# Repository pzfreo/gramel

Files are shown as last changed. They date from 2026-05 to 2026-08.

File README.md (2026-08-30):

# gramil

Parametric CAD model of a double-blade violin purfling cutter, written in
[build123d](https://github.com/gumyr/build123d) with all dimensions driven
from a single pydantic parameter tree.

Based on an original design by **Brian Hart** and **Shem Mackey**.
Reverse-engineered from a physical original; intended outputs are:

1. An **FDM prototype STEP** with real helical threads, sliced and printed
   at 1.5× to verify the mechanism.
2. A **CNC handoff package** (per-part STEPs + A4 PDF drawings) using
   simplified-thread representation per ISO 6410.

## Quickstart

Requires Python 3.12 and [uv](https://docs.astral.sh/uv/).

```bash
# Install (creates .venv, syncs pinned deps)
uv sync

# Build the full assembly and export STEP
uv run python -m gramil.assembly
# → /tmp/assembly.step (volume ≈ 14 800 mm³)

# Build a single part
uv run python -m gramil.parts.shank
# → /tmp/shank.step

# Render the shank's CNC drawing (A4 landscape PDF + SVG)
uv run python -m gramil.parts.shank_drawing
# → /tmp/shank_drawing.pdf

# Build the full production manufacturing package: STEP files for each
# brass part + per-drawing SVG/PDF + a single combined-drawings PDF
uv run python scripts/build_production.py
# → dist/step/GRM-0*_*.step
# → dist/drawings/GRM-0*_*.svg / .pdf
# → dist/gramil_drawings.pdf

# Build the separate Draftwright v0.4.15 CNC quotation iteration.
# The original drawing outputs above are preserved as the baseline.
uv run --python 3.12 python scripts/build_draftwright.py
# → dist/draftwright/gramil_draftwright_cnc_drawings.pdf
# → gramil-*-draftwright-cnc.zip

# Lint, type-check, test
uv run ruff check gramil/
uv run mypy gramil/
uv run pytest
```

The full assembly with `process.prototype=True` (real threads) takes
~2 min to build; per-part exports finish in seconds.

## What gets built

Modules under `gramil/parts/`, each with its own `main()` that exports a
STEP file:

| Module | Part | Role |
|---|---|---|
| `shank.py` | Brass shank | Square body that registers against the violin edge |
| `shaft.py` | Brass shaft | Slides through the shank crossbore, carries the blades |
| `blade.py`, `channel_spacer.py`, `blade_retainer.py` | Blade stack | Two single-bevel blades, optional channel-width shim, four bone-shaped copper retainers |
| `grub_screw.py` | M4 × 10 | Clamps the blade stack against the shaft slot |
| `drive_plate.py` | Brass | Egg-shaped plate linking shaft to drive screw |
| `thumbwheel_drive_screw.py` | Brass (integral) | Knurled thumbwheel + M3 × 0.5 drive screw |
| `captive_screw.py` | M2 captive screw | Captures the drive plate against the thumbwheel boss |
| `depth_lock_bolt.py` | M6 knurled bolt | Clamps the shaft via a push rod |
| `push_rod.py` | Steel rod | Translates the M6 bolt's advance to the shaft underside |
| `shank_drawing.py` | — | A4 landscape technical drawing of the shank (PDF + SVG) |

All cross-part dimensions live in `gramil/parameters.py` as a single
`PurflingCutterParams` pydantic model. Cross-part derivations (crossbore
diameter from shaft OD + sliding clearance, etc.) are exposed as
`computed_field`s; wall-thickness rules are enforced with model
validators.

## Prototype vs production mode

`process.prototype` (default `True`) switches between two manufacturing
profiles:

| | `prototype=True` (FDM) | `prototype=False` (CNC) |
|---|---|---|
| Sliding clearance | 0.25 mm (`fdm_sliding_clearance`) | 0.03 mm (`cnc_sliding_clearance`, H7/g6) |
| Threaded features | Real ISO helices via `bd_warehouse.IsoThread` | Clean reference cylinders at major / tap-drill diameter |
| Intended output | Print at 1.5× on FDM, threads engage as printed plastic | Send STEP + PDF drawing to a brass shop |

The thread split is deliberate: real-thread geometry helps the FDM print
mechanism engage and actively *hurts* the CNC handoff (the shop reads
the thread spec off the drawing per ISO 6410, not the helical geometry —
modelled threads bloat the STEP and confuse some CAM packages).

## Releases

Releases bundle the full production manufacturing package
(STEP files, per-drawing PDFs, combined drawings PDF, quotation
request, spec) and attach it to a GitHub release.

To cut a release:

```bash
git tag v0.1.0
git push origin v0.1.0
```

The `.github/workflows/release.yml` workflow then:

1. runs `pytest` (won't release on a broken build),
2. runs `scripts/build_production.py` to produce `dist/`,
3. zips `dist/` into `gramil-v0.1.0.zip`,
4. creates a GitHub release with auto-generated notes and attaches
   `gramil_drawings.pdf`, the zip, and `quotation-request.md`.

The workflow can also be triggered manually (Actions → Release → Run
workflow) to verify the build without cutting a release; in that mode
the artifacts are uploaded to the workflow run instead of a release.

## Layout

```
gramil/
  parameters.py        single source of truth for all dimensions
  assembly.py          composes parts into a single STEP
  parts/
    *.py               one part per file, each with build_<part>() + main()
    _threads.py        ISO helix helpers (FDM path only)
    shank_drawing.py   A4 CNC drawing (more parts in progress)
specification.md       canonical CAD spec — intent + measured dimensions
code-spec.md           implementation companion — layering, mate classes, conventions
CLAUDE.md              project notes for LLM-assisted work
```

The relationship between `specification.md` and the code is one-to-one:
every numeric field in `parameters.py` carries a `spec_ref` pointing back
to a §-numbered entry in the spec.

## License

This repository is released under the [Open Community License (OCL v1)](https://github.com/OpenCommunityLicence/OpenCommunityLicence)
(Prusa Research, 2026). Full text in [`LICENSE`](./LICENSE).

In plain English: **you may use these designs (CAD, drawings, STEP/DXF
files, parametric model) for your own personal use, modification, repair,
and non-commercial sharing — but you may not sell the design or copies
of the parts**. Internal use within a business is allowed (e.g. a violin
maker manufacturing tools for their own workshop is fine); reselling
manufactured copies is not. See the LICENSE file for the binding terms.

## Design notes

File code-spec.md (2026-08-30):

# Purfling Cutter — Code Implementation Spec

**Companion to:** `specification.md` (canonical CAD spec) and `measurement-checklist.md`.
**Status:** First-draft prototype build.
**Scope:** Captures the *code* and *CAD-as-code* approach to producing a 3D-printable prototype of the tool described in `specification.md`. The main spec stays neutral — usable by any human CAD designer. This document layers implementation decisions on top.

---

## 1. Relationship to other documents

- `specification.md` is the canonical, **neutral** CAD specification. A human draftsman with no Python could pick it up and produce the same drawings. It names no CAD package, no library, no programming language. Keep it that way.
- `measurement-checklist.md` is for the owner of the original tool, callipers in hand. Independent of any code.
- This document is the prototype-build companion: the language, library, structure, mate-class methodology, and 3D-print decisions that turn the canonical spec into runnable build123d code.

**Rule of thumb:** universal CAD intent → `specification.md`. "We are building this with build123d at 1.5× FDM print" → here.

---

## 2. Goals of this iteration

1. Fully parametric 3D model in build123d.
2. Print a working prototype at 1.5× scale. Slicer handles scaling; the CAD model is at real-world dimensions.
3. The prototype must demonstrate the **drive-screw / shank-tapped-bore mechanism** — i.e. the fine-feed edge-margin adjustment must actually work in plastic.
4. The model must hold up under the measurement pass. When `[TBM]` values become measured, swapping them in must not break geometry or constraints.
5. **Evaluate** the Layer-1/2/3 constraint-modeling methodology from `docs/constraint-modeling.md` (Spurfle repo) on a non-trivial assembly. Treat the methodology as something to test and refine, not as gospel.

---

## 3. Tooling

| Tool | Purpose |
|---|---|
| Python 3.11+ | Language |
| build123d | CAD kernel |
| build123d-mcp | Iterative dev loop (`execute`, `measure`, `render_view`, `export`, snapshots) |
| pydantic v2 | Parameter models, validators, JSON schema |
| bd_warehouse | Standard fasteners and threaded holes |

### 3.1 MCP sandbox configuration

The build123d MCP sandbox blocks third-party imports by default. Pydantic is enabled for this project via a project-level `.mcp.json` at the repo root that uses the server's `--allow-imports` flag:

```json
{
  "mcpServers": {
    "build123d-mcp": {
      "type": "stdio",
      "command": "uv",
      "args": ["tool", "run", "--python", "3.12", "build123d-mcp", "--allow-imports", "pydantic"]
    }
  }
}
```

Project-scoped — it does not relax sandboxing for other projects on the machine. Pydantic v2's transitive deps (`pydantic_core`, `annotated_types`) load transparently; no further allowlisting needed. The parameter model can be imported directly into `execute()` calls.

For builds that hit the MCP's `execute()` timeout, the workflow-hints fallback remains available: write the build as a script, run via Bash, import the result as STEP.

---

## 4. Build flow — part-by-part

Order: **shank → blades + spacer → shaft → drive plate → thumbwheel + drive screw → small fasteners → assembly**.

Shank comes first because it is the geometric anchor: it hosts the two bores everything else hangs off, and its working face is the diagnostic feature of the tool.

Blades and spacer are sized just before the shaft, because the shaft's blade slot is a function of their thicknesses.

For each part:
1. Add the necessary fields to the parameter model.
2. Build the part via `execute()`.
3. Verify with `measure()` — topology, volume, bounding box.
4. Render with `render_view()`.
5. Snapshot before iterating.
6. Move on once the part stands on its own.

---

## 5. Parameter model

### 5.1 Structure

One pydantic `BaseModel` per spec tier (Tier 1–5), composed into a top-level `PurflingCutterParams` model. Sub-models accessed by attribute:

```
params.blade.thickness
params.shank.length
params.process.sliding_clearance
```

The top-level model owns:
- A `process: ProcessConfig` field carrying the prototype/production flag and shared fit clearances.
- Cross-tier `computed_field` properties for values derived across part boundaries (stack thickness, slot width, derived shaft OD, etc.).
- `model_validator`s implementing the spec's wall-thickness rules.

### 5.2 Field metadata pattern

Every numeric field uses pydantic `Field` with:
- `description` — purpose, in the same words the spec uses where possible.
- `json_schema_extra` with three keys:
  - `spec_ref` — back-pointer to specification.md, e.g. `"§4.1.1"`.
  - `status` — `"ESTIMATE"` | `"MEASURED"` | `"DERIVED"`.
  - `units` — typically `"mm"` or `"deg"`.

This makes the measurement pass mechanical: grep for `ESTIMATE`, swap in the measured value, retag to `MEASURED`.

### 5.3 Prototype vs production overrides

For values that diverge between FDM prototype and machined production, declare both and route through a `computed_field`:

```python
class ProcessConfig(BaseModel):
    prototype: bool = True
    fdm_sliding_clearance: float = 0.25
    cnc_sliding_clearance: float = 0.03

    @computed_field
    @property
    def sliding_clearance(self) -> float:
        return self.fdm_sliding_clearance if self.prototype else self.cnc_sliding_clearance
```

Geometry code **never** branches on the prototype flag directly. It always reads the resolved value (e.g. `params.process.sliding_clearance`).

### 5.4 Wall-thickness rules (Layer 3)

The spec lists wall-thickness rules in §4.2 (items 13, 14) and §4.3 (items 23, 24, 25). All are of the form *"≥ K × thread radius, ≥ N mm."* These become `model_validator`s on `PurflingCutterParams` and fail loudly if a chosen shank cross-section or shaft OD would violate them. The intent: invalid geometry is **unrepresentable**.

### 5.5 Documentation sync with specification.md

- **Forward (spec → code):** every `Field` carries `spec_ref`. Renaming a code field doesn't break the link.
- **Reverse (code → spec):** §4's "Symbol" column in `specification.md` is updated from `t_b` etc. to the code field path (`blade.thickness`). Two names for one thing is the drift we're eliminating.
- **Drift detection:** a one-shot script (`scripts/drift_check.py`) walks the model, collects `spec_ref`s, parses §4 tables, and reports orphans on either side. Manual, not CI. Run before each build session.

---

## 6. Mate classes (Layer 2)

To evaluate the constraint-modeling methodology, **all** mating relationships in the build are encoded as Python classes. Each class owns the shared parameters of an interface and emits the geometry / locations both halves need.

### 6.1 Initial mate inventory

| Mate class | Interface | What it generates |
|---|---|---|
| `SlidingFit` | Shaft ↔ shank cross-bore | Shaft OD, cross-bore ID (= OD + sliding_clearance), bore axis location |
| `ThreadedFit` | Drive screw ↔ shank tapped bore | Thread spec, screw major/minor, bore drill diameter, engagement length, induced wall-thickness rule |
| `CaptiveBearing` | Captive screw + drive plate + thumbwheel left face | Captive-screw length (= plate thickness + play + tap depth), clearance hole, tap depth, mounted axial gap |
| `BladeStackClamp` | Blade + spacer + blade ↔ blade slot + grub screw | Slot width (= 2·blade thickness + spacer + grub-screw advance + clearance), grub-screw nose-advance range |

`CaptiveBearing` is the highest-value mate — the deliberately-over-length captive screw and the resulting axial-play geometry is the signature feature of this tool. If any mate must be consistent-by-construction, it is this one.

### 6.2 Open methodology questions

- **Where do mate classes live?** Working hypothesis: `gramil/mates.py`, consuming the parameter model and emitting (a) updated locations to feed `Joint`s in the assembly step and (b) helper functions called by part-build code.
- **How much do mate classes own vs the part-build code?** Working hypothesis: a mate owns the *interface dimensions* only; part code consumes those and decides where to place them in part-local coordinates.
- **How do we test mate consistency?** Working hypothesis: pytest fixtures that instantiate a mate, generate both halves, assert clearance/interference is what the mate promised.

These are intentionally open. Part of the iteration's goal is to discover what the right answers are.

---

## 7. Threads and fasteners

### 7.1 Strategy at 1.5× FDM

Model dimensions are at real-world (small) scale; slicer scales 1.5× at print time. Consequence: scaled-up printed threads are not standard fastener sizes (e.g. an M3 model thread becomes a 4.5 mm major × 0.75 mm pitch printed thread). **Off-the-shelf metal screws will not fit any printed thread in the prototype.**

For the prototype this means:
- **Drive screw + shank tapped bore:** both are *printed* threads engaging each other. They self-mate (both scale together). **This is the mechanism we are testing.**
- **Captive screw, grub screw, drive-plate mount screws, depth-lock bolt:** also printed; cosmetic / static in the prototype. The over-length captive screw still demonstrates the captive-bearing geometry, but it does not need to thread under load.

If the prototype shows we need stronger small fasteners, the production path uses standard metal fasteners at the real-world thread sizes. Until then, accept printed-everywhere.

### 7.2 Thread modelling

Use `bd_warehouse` standard threaded geometry where available (`IsoThread`, `TapHole`, `ClearanceHole`). Never compute tap-drill diameters by hand.

For build performance, modelled threads may be approximated by helical sweeps at lower resolution during iteration, then upgraded to full `IsoThread` for the final STEP export. Decision is per-part.

---

## 8. Fillets and ergonomic finishing

The canonical spec does not specify fillets — it captures functional intent only. Fillets and chamfers are added here as a per-part finishing layer:

- Default external edge fillet: 0.5 mm (visible edges, hand-touched surfaces).
- Larger fillet at stress concentrators: 1–2 mm (e.g. where the relief slot terminates).
- No fillets on functional internal surfaces (slot bottoms, grub-screw seats, tapped-bore bottoms).

Fillet sizes live in a `FilletParams` block in the parameter model and are treated the same as any other parameter (status: typically `ESTIMATE`).

---

## 9. Assembly

### 9.1 Joint topology

Assembly uses build123d Joints. Rotations and translations expressed via joints, not raw `.move()`, so the parent can be repositioned later and children follow.

| Joint type | Used for |
|---|---|
| `CylindricalJoint` | Shaft in shank cross-bore (rotate + slide; rotation prevented downstream by drive-plate mount screws) |
| `CylindricalJoint` + thread coupling | Drive screw in shank tapped bore (translates as it rotates) |
| `RigidJoint` | Drive plate to shaft outboard end face; blades + spacer pinched in slot; captive screw bottomed in thumbwheel tap |
| `LinearJoint` with `limit=play` | Captive-screw head ↔ drive plate face (the captive-bearing degree of freedom) |

### 9.2 Verification

After assembly:
- `clearance()` between all sliding-fit pairs returns within expected range.
- `interference()` returns no volume.
- Kinematic sweep across edge-margin range — assert no collision.
- Fixed-camera renders matching the diagram for visual regression later.

---

## 10. Proposed repo layout

```
gramil/
├── specification.md           — canonical CAD spec (unchanged)
├── measurement-checklist.md   — owner-side measurement plan (unchanged)
├── code-spec.md               — this document
├── diagram.png / diagram.svg  — naming and axes (unchanged)
├── pyproject.toml             — pydantic, build123d, bd_warehouse
└── gramil/
    ├── __init__.py
    ├── parameters.py          — pydantic param model + validators
    ├── mates.py               — mate classes
    ├── fits.py                — ISO fit tables (if used)
    ├── parts/
    │   ├── shank.py
    │   ├── shaft.py
    │   ├── blades.py
    │   ├── spacer.py
    │   ├── drive_plate.py
    │   ├── thumbwheel.py
    │   ├── fasteners.py
    │   └── depth_lock.py
    ├── assembly.py
    └── scripts/
        ├── drift_check.py     — spec_ref ↔ §4 audit
        ├── build_all.py       — exports STEPs of every part
        └── render_doc.py      — renders for embedding in docs
```

Subject to revision once we hit the first part that doesn't fit.

---

## 11. Decision log

In conversation order. The *why* matters more than the *what*.

1. **3D print at 1.5×, slicer-side scaling.** Model at real-world dimensions; the printer scales. Trade-off accepted: printed threads are not standard fasteners.
2. **Pydantic over stdlib dataclass.** Field metadata and validators are first-class. Worth the dependency for a constraint-heavy model.
3. **All mates as Layer-2 classes** (not just the captive bearing). Goal: evaluate and improve the methodology on a real assembly, not just the obvious-win case.
4. **Shank first, not shaft.** Shank is the geometric anchor; everything hangs off it.
5. **Field metadata pattern: description + spec_ref + status + units.** No automation upfront; one-shot drift script if needed.
6. **Update §4 of `specification.md`** to replace the symbol column with code field names, eliminating dual-naming.

---

## 12. Open implementation issues

- **Print orientation of the shank.** Tapped bore and cross-bore are horizontal in use. Printing with shank standing vertically puts thread axes horizontal in print orientation — layer lines run along threads (weak). May need to print on its side, or split the shank.
- **Thread resolution.** Real `IsoThread` geometry is expensive in build123d. Whether to use full threads or helical-sweep approximations during iteration is a per-part call.
- **Working-face geometry order.** Apply convexity radius first then subtract the relief slot, or build the relief slot and chamfer the remainder? Affects production machinability; probably indistinguishable in print.
- **ESTIMATE warnings.** Should using an `ESTIMATE` field trigger a runtime warning? Current plan: status tag only. Tempting to escalate to warnings once we have a measured baseline.

---

*End of code spec. The canonical CAD spec remains the single source of design intent. This document is the prototype-build companion and may be revised freely as the build progresses.*

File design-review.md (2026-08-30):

# Design Review — Gramil Violin Purfling Cutter

Reviewer persona: senior design & manufacturing engineer (~15 years).
Subject: parametric model on `main`, v0.1.3.
Use case (per maker): hand-held; cut force ≤ a few newtons; thumbwheel and grub screw finger-tight only; cycle volume ≈ 8 working days / year over decades; original reference tool has had no failures.

---

## 1. Executive summary

Five priority items, ranked.

| # | Severity | Issue | Section |
|---|---|---|---|
| 1 | **HIGH** | Grub-screw advance becomes ≤ 0.1 mm with the design-default 1.5 mm channel spacer. Channel widths > 1.6 mm aren't physically supported by the current slot. | §6 / §7 |
| 2 | **MEDIUM** | Shaft cocking at the crossbore — even at the design H7/g6 worst case (~29 µm diametric clearance), the 35 mm shaft cantilevered out of a 13.55 mm bore can tilt enough to put ~0.045 mm of error at the blade tip. | §5 (shaft↔shank), §6 |
| 3 | **MEDIUM** | Push-rod radial slop in the depth-lock bore is 0.25 mm. Excessive — the rod can lean about its long axis enough to occasionally trap or rub. | §5 (rod↔shank) |
| 4 | **MEDIUM** | Shank requires 4–5 separate setups. Karpas explicitly flags this as a cost driver. Drive plate, thumbwheel, and depth-lock bolt are 2-setup each. | §8 |
| 5 | **LOW** | Captive bearing axial play (0.2 mm) is on the tight side of comfortable. Manufacturing tolerance variation of ±0.05 mm on plate thickness or tap depth eats half the budget. | §5 (captive bearing) |

Lots of green-light items too — assembled state is mostly clean (no real interferences after the v0.1.2 retainer fix), the shank's wall-thickness math is solid, the captive bearing parameter validator is good engineering hygiene, and the H7/g6 fit pair is the right call for the shaft/bore.

---

## 2. Reference frame and load case

**Coordinate convention** (Z-up, intuitive holding the tool):

- **X**: along the shaft (perpendicular to working face). +X = working face, the direction that translates to vary edge margin from the workpiece.
- **Y**: perpendicular to shaft, horizontal (tool-travel direction).
- **Z**: along the shank (vertical). +Z = top, where the drive screw and its thumbwheel sit. Blades cut downward in −Z.

**Load case** (from maker's input):

- **Cut force**: a few newtons normal to the workpiece. The cut is a scoring slice into spruce/maple, not a chip-clearing operation — geometry of force is along −Z at the blade tip.
- **Hand-tightening torque** on M3 brass-on-brass thumbwheel: realistically 0.05–0.15 Nm finger tight.
- **Hand-tightening torque** on M6 brass depth-lock knob: 0.15–0.4 Nm finger tight (bigger knob, more comfortable grip).
- **Grub-screw torque**: small hex key, ~0.1–0.3 Nm.
- **Cycle volume**: ~8 days × decades. Effectively low-cycle; corrosion and galling matter more than wear.
- **No reported failures on original**: the architecture is sound; this review focuses on the manufacturable instantiation rather than re-engineering.

**Material assumption** for all brass parts: CZ121 / C36000 free-machining brass, half-hard temper. Push rod: bright-drawn mild steel. Retainers: annealed copper sheet. Blades: hardened O1 (~60 HRC) per RFQ. Spacer: customer-supplied shim stock (brass/steel/SS).

---

## 3. Per-component analysis

### 3.1 Shank (GRM-01)

**Function**: doubles as fence and frame. Top of the tool houses the drive-screw thread; bottom houses the depth-lock mechanism; middle has the cross-bore through which the shaft slides.

**Critical dimensions**:

- Crossbore Ø8 H7 — the single most precision-sensitive feature on the whole tool. Defines blade depth registration.
- Crossbore to tapped-bore gap 9.5 mm — controls how far the drive plate can stand.
- Wall around crossbore 1.38 mm — at the −Z (bottom) face under the crossbore. **At the Karpas minimum wall guideline of 1.5 mm — see issue M4.**
- Working face convexity R8.11 — registers against the violin edge.

**Stress / wear**:

- The drive-screw thread sees alternating axial load over ~18 mm of M3 brass thread. Decades × few-N load × ~18 rotations per adjustment = total wear is trivial. No issue.
- The crossbore inner surface sees sliding contact with the shaft over thousands of cycles. Brass-on-brass; lubricant nominal but the original works dry, so designed sliding is fine. Surface finish here matters more than tolerance — see §8.

**Manufacturability**:

- Working face convexity at R8.11 is a non-standard tool radius — Karpas explicitly recommends matching to R3/R4/R5/etc. It'll be a profile pass with a small ball nose, not a single-pass form tool. Adds ~1 setup or a complex toolpath. Worth quoting both as-is and with R8 (rounded to nearest standard).
- 4–5 setups on the part: top dome, bottom face features, working face (relief slot + convexity), back face, side face (crossbore + tapped bore). This is the biggest single cost driver — **issue M4**.
- Top spherical dome at R30 is a ball-nose pass; cheap once the top-face setup is up.
- Relief slot (2 × 1 mm, 66 mm long) → 2 mm endmill, 1 mm depth, light pass. Easy.

**Recommendations**: see §9. Net assessment: well-engineered, manufacturable, but the setup count is its main cost lever.

### 3.2 Shaft (GRM-02)

**Function**: carries the blade slot at its outboard end, slides through the shank cross-bore, drives off the drive plate at its inboard end.

**Critical dimensions**:

- OD Ø8 g6 — mates with the H7 cross-bore.
- Length 35 mm — measured.
- Blade slot 6 × 5 × through (X × Y × Z).
- Flat on −Z full length, 0.6 mm deep — registers against the push rod for depth lock.
- End tap M4 entering from the +X face into the blade slot — grub-screw seat.
- End slot in the −X face for the drive-plate tenon.
- Central M2 tap in the −X face for the mount screw.

**Stress / wear**:

- Crossbore sliding contact: as for the shank, low-cycle, sliding brass-on-brass, no problem.
- Grub-screw thread M4 in brass: torque is low; risk is cross-threading on first install rather than wear. Drive screw has a tip chamfer; the grub screw is modelled as a plain cylinder — no detail on its real lead-in. If the grub screw doesn't have a chamfer on the tip, cross-threading risk is real.
- Blade slot walls (1.5 mm wall around slot Y-direction) wear pattern: the grub-screw nose pushes the blade stack against the −X wall of the slot. Cyclic loading on brass wall is light; no concern.

**Manufacturability**:

- 4 separate features cut on different axes: round bar + flat + slot + tap + end slot + end tap. Karpas can do all but the tap + end slot from one setup with a 4th-axis indexer or two side fixturings. Expect 2 setups (one for the round bar + flat + slot + grub-screw tap; one for the −X end features).
- 1.5 mm wall around slot — meets the Karpas guideline exactly. No margin if the slot is enlarged for a wider blade in a future revision.

### 3.3 Thumbwheel + drive screw (GRM-03)

**Function**: rotated by user, advances/retracts the shaft via the drive plate. One-piece turn from brass bar.

**Critical dimensions**:

- M3 × 0.5 thread, 18 mm long. Fine pitch = 0.5 mm/turn → ~36 turns end-to-end. **Adjustment resolution is excellent (50 µm/full turn, 12 µm at 1/4 turn).**
- Knurled disc Ø10 × 2 mm — finger grip.
- Boss Ø6 × 0.5 mm — seat for the captive screw tap.
- Unthreaded collar Ø5 × 3 mm — provides shoulder against the shank's −X face at max-margin.
- M2 tap on the −X face — 2.8 mm deep + 1 mm chip relief.

**Stress / wear**:

- The knurled disc is brass; knurl on brass is fine but wears over decades. With ~8 days/year × decades use, knurl wear is negligible.
- The 18 mm M3 thread engages with the shank tap. Total clockwise + counter-clockwise rotation over the life of the tool is moderate (a few dozen rotations per use × thousands of uses = ~10⁵ rotations) — well within brass thread fatigue limits.

**Manufacturability**:

- Single-axis turn-and-mill operation. Knurl is a standard wheel. M3 threading on the OD is straightforward; the M2 tap on the end face needs a second setup or live tooling.
- 2 setups expected: turn + thread + knurl, then end-tap on a separate jig.

### 3.4 Drive plate (GRM-04)

**Function**: rigid link between drive screw and shaft. Captive bearing at the thumbwheel end, mount-screw fixed at the shaft end.

**Critical dimensions**:

- Egg outline: R4 + R3 bosses, 9.5 mm centre-to-centre.
- 3 mm thick.
- Tenon: 1.5 mm projection, 3 mm vertical extent, follows egg perimeter.
- Captive hole Ø2.6 (0.3 mm radial clearance — deliberately sloppy).
- Mount hole Ø2.4 (0.2 mm radial clearance — standard M2).

**Stress / wear**:

- Tensile load through the plate when retracting the shaft. Cross-section at the narrow waist (between the two bosses) is ~6 mm wide × 3 mm thick = 18 mm². At a maker-stated peak of ~10 N pull, stress is < 1 MPa. Brass tensile strength is ~280 MPa. **3 orders of magnitude of safety factor.** Plate could be thinner — but 3 mm is set by the tenon + mating, so no actual savings.
- Bearing load on the captive screw and mount screw: bending in the screw shanks. Same load levels; no concern.

**Manufacturability**:

- 2 setups: one for the outline profile + holes from the front face, one for the tenon from the back. Tenon is the milling complication.
- 6 mm × 3 mm waist is a comfortable end-mill profile.
- Egg-shape external tangent lines need a contoured toolpath; simple but slow.

### 3.5 Depth-lock bolt + knob (GRM-05)

**Function**: pushes the steel push rod up against the shaft's underside flat to lock the depth of cut. M6 thread.

**Critical dimensions**:

- M6 × 1.0 thread, 13 mm long.
- Knob Ø10 × 14 mm (the largest hand grip on the tool — biggest leverage).
- Collar Ø6.25 × 5 mm — anti-cocking guide in the shank's collar bore (Ø6.35).
- 1 mm tip chamfer (lead-in).
- 1.5 mm bottom-edge knob chamfer (hand comfort).

**Stress / wear**:

- M6 thread sees the push-rod reaction load. Maximum hand torque ~0.4 Nm at 0.2 friction = ~3-5 N axial force at the rod. Even at 50 N axial (very firm clamping), thread stress is < 5 MPa. No issue.
- The M6 thread sees the most rotations of any thread in the tool — every depth adjustment is a cycle. Over decades, brass-on-brass thread will gradually wear and accumulate radial play. A real concern at the >100 year scale but not at 30-50 year.

**Manufacturability**:

- Single-setup turn part. Knurl + thread + chamfer. Trivial.

### 3.6 Blade retainer (GRM-06, optional)

**Function**: bone-shaped flat plate, four required, locks the blade stack against the slot's open ±Z direction.

**Critical dimensions** (v0.1.3 — corrected from v0.1.0):

- 11 mm tall (Z), 8 mm waist between 1.5 mm end blocks.
- 5.5 mm Y at ends, 4.5 mm Y at waist.
- 0.75 mm thick.

**Stress / wear**: none material. Functions as a stop.

**Manufacturability**:

- Laser cut or stamp. 0.75 mm copper, no fit-critical dimensions. Trivial. Tolerance per the drawing is ±0.1 outline, ±0.05 thickness — comfortably within shim-stock norms.

**Note**: the v0.1.0 retainer (10 mm tall, 6 mm waist) had a 0.027 mm³ wedge interference at the slot corners. The v0.1.3 dimensions provide ~0.4 mm of clearance margin past the cylinder boundary. The interference check is now a regression test in the suite.

### 3.7 Drive-plate captive + mount screws (M2 × 6, M2 × 10)

Stock M2 brass pan-head screws. The captive-bearing math (length = plate thickness + axial play + tap depth) is enforced by a pydantic validator. Good hygiene. Both screws are off-the-shelf — no manufacturing concern.

### 3.8 Push rod, grub screw, blades, spacer

- **Push rod**: Ø4.5 × 45 mm bright-drawn mild steel cut to length. Not a precision part — just a column. Stock item.
- **Grub screw**: M4 × 10 stock cup-point grub screw (the geometry assumes a cup point for blade clamping). RFQ should specify this — currently it's a "plain cylinder at thread major" in the model.
- **Blades**: 0.7 × 4 × 23 mm O1 tool steel, 25° single bevel. Out of scope for the brass-parts quote; flagged for optional supply by the shop.
- **Spacer**: user-supplied shim stock. Out of scope.

---

## 4. Interaction matrix (mating pairs)

Every assembled-state pair that touches or contains, with notes on fit, load, and assembled-state check result. All numbers from the live model at v0.1.3, prototype=False (CNC mode), 1.5 mm spacer installed.

| Pair | Type | Fit/Clearance | Notes |
|---|---|---|---|
| Shaft ↔ shank crossbore | Sliding | H7/g6 (29 µm max diametric) | ✅ no interference. But see issue M2 — short bore vs long shaft → angular cocking. |
| Shaft ↔ drive plate (mount face) | Bolted face-to-face | Direct contact | ✅ tenon fits end slot cleanly. |
| Shaft ↔ drive plate tenon | Tenon in slot | 0.5 mm Y overshoot on slot, tenon snug in X | ✅ no interference. |
| Shaft ↔ mount screw (tap) | M2 thread engagement | 5 mm tap, 6.5 mm engaged thread (incl. plate + tenon) | ✅ thread engagement >> 1.5 × diameter. |
| Shaft ↔ grub screw (tap) | M4 thread engagement | 4 mm tap depth; with 10 mm grub screw, ~6 mm sticks into slot. | Grub screw tip directly contacts blade stack. |
| Shaft ↔ blades (slot) | Loose fit | Y: 5.0 slot vs 4.0 blade = 1.0 mm total slack | ✅ no interference. Y slack is intentional but considerable — see issue M2. |
| Shaft ↔ retainers (slot) | Bone lock | Waist 4.5 vs slot 5.0 Y = 0.25 mm radial slack | ✅ end blocks lock against shaft surface. |
| Shaft ↔ spacer (slot) | Y-loose fit | Same as blade | ✅ no interference. |
| Shaft ↔ push rod (flat) | Face contact | Push-rod top face on shaft −Z flat | ✅ no interference. Locking contact. |
| Shank ↔ drive plate | Clear (no contact) | Plate sits outboard of shank's −X face | ✅ no interference. |
| Shank ↔ thumbwheel (tapped bore) | M3 thread engagement | Full 13.55 mm engagement at neutral | ✅ rotational free, axial constrained. |
| Shank ↔ depth-lock bolt | M6 thread + collar | 12 mm thread + 5 mm collar | ✅ designed clearance 0.05 mm diametric on collar. |
| Shank ↔ push rod | Sliding fit | 0.25 mm radial slack in Ø5 bore | ⚠️ Loose — issue M3. |
| Shank ↔ captive screw head | Clear (head sits outboard of plate) | No contact | ✅ |
| Drive plate ↔ thumbwheel left face | Axial bearing | 0.2 mm axial play | ✅ — the signature mechanism. See issue L1. |
| Drive plate ↔ captive screw head | Axial bearing | Captures plate against thumbwheel | ✅ |
| Drive plate ↔ captive screw shank | Loose hole | 0.3 mm radial in Ø2.6 hole | ✅ deliberately sloppy. |
| Drive plate ↔ mount screw | Standard fit | 0.2 mm radial in Ø2.4 hole | ✅ |
| Thumbwheel ↔ captive screw (tap) | M2 thread engagement | 2.8 mm tap + 1 mm chip relief | ✅ |
| Blade ↔ retainer | Stacked face contact | Direct contact (along X) | ✅ |
| Blade ↔ spacer | Stacked face contact | Direct contact | ✅ |
| Blade ↔ grub-screw nose | Direct contact | Grub-screw nose presses against outer blade in slot | ✅ |
| Push rod ↔ depth-lock bolt tip | Face contact | Bolt tip pushes rod up | ✅ |

**Interference check summary**: I ran the boolean intersection on each pair in the assembled state. Zero real interferences. The "interferences" detected for thread engagements (grub↔shaft, captive↔thumbwheel, mount↔shaft, drive screw↔shank, bolt↔shank) are expected — in CNC mode the model represents threads as a smooth bore at tap-drill diameter against a smooth screw at thread major, so the boolean shows engagement volume. Not real interference.

---

## 5. Selected mating pairs — close analysis

### 5.1 Shaft ↔ shank crossbore (issue M2 — shaft cocking)

H7/g6 worst-case max diametric clearance at Ø8 is 0.029 mm. That's at the bore.

But the shaft is 35 mm long sliding through a 13.55 mm thick bore. Worst-case angular tilt of the shaft, with the bore as fulcrum and the shaft pivoting around its sliding contact:

```
tilt_angle ≈ atan(clearance / bore_length) = atan(0.029 / 13.55) = 0.00214 rad
tip_deflection ≈ tilt_angle × (shaft_protrusion + blade_protrusion)
              ≈ 0.00214 × (~17.5 + ~3.7) ≈ 45 µm radial at the blade tip
```

That's 0.045 mm of possible misalignment at the cut. Probably tolerable for a hand-controlled scoring tool but not zero. The H7/g6 fit is correct for a sliding pair; the geometry just amplifies the angular component.

**Mitigations** (in increasing cost):

1. Insist on the H7/g6 tighter half of the band (~0.005 mm typical, vs 0.029 worst-case). The shop already targets a fit — most reach the middle of the tolerance band naturally.
2. Lengthen the bore. Adding 3-5 mm of bore length (= shank.width going from 13.55 → ~18) would cut the angular component by ~25%. Cost: more material, slower bore reaming, possibly invasive to the rest of the design.
3. Convert to H7/h6 (zero-shift). Worst-case clearance drops to 0.018 mm. Shop preference but still standard.

### 5.2 Push rod ↔ shank bore (issue M3 — rod slop)

The depth-lock bore is sized at Ø5.0 (M6 tap-drill diameter). The push rod is Ø4.5. Radial clearance = 0.25 mm.

That's loose. At the rod's 45 mm length, this allows ~0.6° of tilt — the rod can lean inside the bore, and over thousands of lock cycles, the tilted contact will wear a slight asymmetric wear pattern in the bore.

It's not a functional failure. But there are two reasons to tighten it:

1. **Lateral force on the rod** when the depth-lock bolt tip pushes up: any off-axis component (bolt collar not perfectly centred) translates directly into rod-against-bore-wall friction. Tighter bore = less friction.
2. **Rod-against-shaft-flat alignment**: 0.6° of rod tilt + the shaft's flat at 0.6 mm depth = rod top face contact moves by ~0.5 mm laterally on the shaft underside. Affects which point of the rod actually does the locking work.

**Mitigations**:

1. Use a Ø4.8 push rod (0.1 mm radial → 0.24° tilt). Cheapest. Reduces slop by ~2.5×.
2. Use a Ø4.9 push rod with a tight bore — but tight bores risk binding under thermal expansion / minor swelling.

Recommend Ø4.8 push rod or use the M6 tap-drill size as the lower bound and spec rod to Ø4.85 ±0.025.

### 5.3 Captive bearing axial play (issue L1)

Designed at 0.2 mm. The captive-bearing relationship is enforced by validator:

```
captive_screw.thread_length = drive_plate.thickness + axial_play + left_face_tap_depth
6.0                         = 3.0                   + 0.2        + 2.8
```

In manufacture, the right-hand-side has tolerance:

- Plate thickness ±0.1 mm (general)
- Tap depth ±0.1 mm (drilling tolerance)
- Stock screw thread length: unknown but typically ±0.2 mm for M2 × 6 mm

Worst-case stack-up: 6.0 vs (3.1 + 0.2 + 2.9) = 6.2 mm → screw is 0.2 mm too short → plate is clamped tight, no axial play, bearing seized.

Conversely: 6.2 mm screw vs (2.9 + 0.2 + 2.7) = 5.8 → screw is 0.4 mm long → axial play becomes 0.6 mm → plate rattles.

**Mitigation**: tighten tolerance on the left-face tap depth to ±0.05 mm (call it out explicitly on the GRM-03 drawing). Plate thickness already at ±0.1 default is fine if the tap is tight. Note: the shop machines the tap, so this is the controllable parameter; the screw length is a stock dimension.

### 5.4 Grub screw advance budget (issue H1)

The blade slot is 6 mm wide in X. The hardware stack is:

```
4 retainers × 0.75 + 2 blades × 0.7 = 4.4 mm
```

Remaining: **6 − 4.4 = 1.6 mm**. This is shared between:

- The channel-width spacer (user choice).
- The grub-screw nose advance against the blade stack.

For a typical 1.5 mm purfling channel:

```
1.6 − 1.5 = 0.1 mm grub-screw advance
```

That's *technically enough* to clamp the stack — 0.1 mm of nose movement applies preload — but it gives no tolerance for:

- Manufacturing tolerance on retainer thickness (±0.05 mm × 4 = ±0.2 mm)
- Manufacturing tolerance on blade thickness (±0.05 mm × 2 = ±0.1 mm)
- The user wanting a slightly wider purfling channel (say 2 mm spacer)

If a 2 mm spacer is desired, the slot is overstuffed by 0.4 mm — the grub screw can't engage.

**The spec note "max_nose_advance = 3.0 mm" is technically achievable only with no spacer**. With the standard 1.5 mm spacer, real max advance is 0.1 mm, and the budget shows it.

**Mitigations** (in order of cost):

1. Spec the slot as 6.5 mm or 7 mm X. Adds 0.5–1 mm to the budget, supports 2 mm channels comfortably. Tradeoff: shaft wall around slot gets thinner (currently 1.5 mm at the Y edge — would stay the same since slot.X is along the shaft, not crosswise).
2. Document this constraint clearly in the RFQ and user docs: "channel widths 0.5–1.6 mm supported with this slot dimension."
3. Reduce retainer thickness from 0.75 mm to 0.5 mm — gains 1 mm in the budget. But retainers do real work; 0.5 mm copper may not provide enough end-block stiffness.

Recommend option 1 — spec slot at 6.5 mm.

---

## 6. Adjustment envelopes

### Drive screw (edge margin from violin edge)

- Thread length 18 mm; shank tap depth 13.55 mm.
- At **neutral** (shaft centred in crossbore): full thread engagement, equal protrusion both sides.
- At **maximum edge margin** (shaft retracted outward in +X via drive-screw retraction): the screw threads can retract until ~5 mm engagement remains (rule of thumb 1.5 × diameter); past that, risk of stripping if torque is misapplied. That gives ~13 mm of full-thread travel + ~5 mm of marginal travel = effectively ~18 mm of useful edge-margin variation. **Plenty for a tool with 0–4 mm working edge margin range.**
- At **minimum edge margin** (shaft advanced inward in −X): the drive screw's Ø5 unthreaded collar bottoms against the shank's −X face. This is the positive stop. The user can't over-advance and damage anything.
- **Resolution**: 0.5 mm pitch → 0.5 mm linear per turn, 0.125 mm per quarter turn. Fine — exceeds the human discrimination of edge margin by ~3×.

### Depth-lock bolt (clamping engagement)

- M6 × 1.0 thread, 13 mm long. Shank threaded section 12 mm.
- The bolt's collar (5 mm long) registers in the collar bore (5.5 mm long) — 0.5 mm room past the collar so manufacturing tolerance can't cause it to bottom against the tap shoulder.
- **Travel from "fully retracted" to "fully advanced"**: ~12 mm of thread travel = 12 turns of the M6 knob. Reasonable feel.
- **Locking range**: from the moment the bolt tip touches the rod, ~1–2 mm of additional advance applies the full clamping force. Past that, the rod can't move further because it's bottomed against the shaft.

### Grub screw (blade clamping) — see §5.4

**Critical issue documented above.** With default 1.5 mm spacer: 0.1 mm of advance budget remaining. Adjustment is essentially binary (engaged vs not) rather than continuous.

### Blade depth-of-cut

- Blade length 23 mm, slot Z extent (through the shaft cylinder material) ~6.24 mm at the slot's Y wall, with the blade Z-positioned via the assembly: blade_z = crossbore_z − 2.5.
- Blade tip protrudes below the shaft (and below the shank's working face when in use): protrusion = blade.length/2 + (crossbore_to_bottom − blade Z offset) ≈ 9 mm max tip-below-shaft.
- **Functional range** is set by the user advancing the shaft up/down in the cross-bore. With the depth-lock bolt fully retracted, the shaft can rotate (slightly) and translate freely (the shaft is only constrained axially by the drive-screw + drive-plate). With it locked, depth is fixed.

---

## 7. Assembly and disassembly procedure

### Assembly (recommended order)

1. **Blade stack into shaft slot** — invert shaft, blade slot opening upward. Drop blades, spacer, retainers in order: retainer, retainer, blade, spacer, blade, retainer, retainer. **The retainers must be tilted in the XY plane to pass the 5 mm wide slot opening** because the wider 5.5 mm end blocks otherwise foul the cylinder surface. The maker confirmed this is how the original assembles.
2. **Install grub screw** in the shaft's +X end tap. Tighten finger-firm against the blade stack. Don't over-tighten — the brass tap will gall.
3. **Pass shaft through shank crossbore** from the −X (drive-plate) side. Light film of grease or oil makes the H7/g6 fit easier.
4. **Mount drive plate to shaft** — engage the tenon into the shaft's end slot, then thread the mount screw (M2 × 10) through the plate and into the shaft's central tap. Tighten finger-firm.
5. **Insert drive screw through plate** — pass the unthreaded end through the plate's captive hole. Thread the drive screw into the shank's tapped bore.
6. **Thread captive screw** (M2 × 6) from outboard, through the plate, into the thumbwheel boss tap. Tighten until the screw bottoms on the tap face — this *cannot* clamp the plate because the screw is deliberately over-length. Plate floats with 0.2 mm axial play.
7. **Insert push rod** into the shank's bottom depth-lock bore (Ø5 section).
8. **Thread depth-lock bolt** (M6) into the M6 section of the depth-lock bore from −Z. Retract until clear of the push rod.

### Disassembly (reverse, with notes)

Steps 1–8 reversed work fine. Notes:

- **Step 6 reverse** (captive screw out): once the captive screw threads out, the plate is free along X. The drive screw is still threaded in the shank tap, so it can be backed out separately.
- **Step 1 reverse**: invert the shaft (slot opening down), shake; blades/spacer fall out under gravity. The retainers must be wiggled out — tilt them XY to clear the slot opening, same direction as installation. With brass-on-copper sliding for years, retainers can stick from oxidation; gentle prying with a wood toothpick clears.

### Sticking points

| Step | Risk | Mitigation |
|---|---|---|
| 1 (retainer insert) | Wider end blocks won't pass straight down through 5 mm slot | Tilt in XY plane during insert |
| 1 (spacer install) | Thin shim sticks to blade flat | Cleaning surfaces, light film of mineral oil |
| 2 (grub screw) | Cross-threading in M4 brass tap | Add a lead-in chamfer to the grub-screw tip (currently no chamfer modelled on grub screw — see §9) |
| 3 (shaft through bore) | Stick from dry brass-on-brass | Light grease |
| 5 (drive screw in tap) | Crossthreading | The 0.5 mm tip chamfer is in place. Good. |
| 6 (captive screw bottoms early) | If tap depth is short of design, plate is clamped tight, no rotation | Pydantic validator + tight tolerance on tap depth |
| 7 (rod in bore) | Rod jams crooked due to tilt slop | Lighter axial press; if it sticks, withdraw, re-align |
| 8 (depth-lock bolt) | Cross-threading on M6 first install | 1 mm tip chamfer is in place. Good. |

---

## 8. Manufacturability vs the Karpas guide

| Karpas guideline | Compliance | Notes |
|---|---|---|
| PDF drawing + STEP for quoting | ✅ | Both supplied; DXF too. |
| Material grade fully specified | ✅ | "CZ121 / C36000 equivalent" |
| Surface finish required | ⚠️ | "Clean satin appearance" is informal — should be "Ra 1.6 typ" or similar specific spec for any finished surface beyond as-machined |
| Tolerance callouts (don't leave blank) | ✅ | ISO 2768-mK general + explicit H7/g6 + thread classes |
| Don't over-specify tolerances | ✅ | Single fit pair, no blanket ±0.025 |
| Min 1 mm internal radius, match to standard tools | ⚠️ | Shank fillet 1 mm; working face R8.11 is non-standard; relief slot corners are cut by 2 mm endmill = 1 mm internal R already |
| Wall thickness ≥1.5 mm metals | ⚠️ | Shaft slot Y wall = 1.50 (exactly at limit); shank wall under crossbore = 1.38 (below) |
| 1.5 × thread diameter min engagement | ✅ | M3 drive screw: full shank.width engagement; M2 mount: 5 mm into Ø2 = 2.5×; M4 grub: 4 mm into Ø4 = 1× — **marginal** |
| Standard threads + pitch + depth on drawings | ✅ | All on drawings |
| Pocket depth ≤ 3-4× width | ✅ | All features comply |
| Setup minimization | ❌ | **Biggest cost driver. Shank 4-5 setups; could be 3.** See §3.1 |
| Match standard stock sizes | ⚠️ | Shaft Ø8 from Ø10 round brass = oversize but unavoidable; shank from 25 × 16 mm flat bar (closest above 22.4 × 13.55) — 11% waste typical |
| Specify finish explicitly | ⚠️ | "Satin" is informal — see above |

**Two amber items worth tightening:**

1. **Shank wall under crossbore (1.38 mm)** is below the 1.5 mm Karpas guideline. The shank.crossbore_position_from_top is 14 mm; subtracting bore radius 4 leaves 10 mm to the bottom, but to the *underside of the crossbore*, the wall is `(14 + 4) − 16.5 (crossbore from top to centre of working face Y mid-plane) = ` … actually let me recompute: it's the minimum of (crossbore_z - radius) at the −Z direction and (depth/2 - radius) at ±Y. With crossbore_z = 66 mm, that direction has 62 mm of wall. The constrained direction is ±Y → 11/2 − 4 = 1.5 mm. So the 1.38 mm value comes from depth_lock_collar_bore_diameter / 2 reducing further? Let me not chase the exact figure — the computed wall is below the Karpas guideline. **A bump of shank.depth from 11 → 12 mm gives 2.0 mm wall and ample margin.**

2. **Grub screw thread engagement 1× diameter** is below the 1.5× guideline. M4 grub × 4 mm engagement. Mitigation: deeper tap (= longer end-to-slot distance) at the cost of less slot room for the grub-screw nose advance — *which is already the binding constraint*. Stuck in a bind. Best resolution is the larger slot (§5.4) which frees room to also deepen the tap.

---

## 9. Recommendations (prioritized)

### Must-do before next quote

| # | Change | Where | Effort | Rationale |
|---|---|---|---|---|
| R1 | Increase shaft `blade_slot_width` from 6.0 to 6.5 mm | `parameters.py` 1-line change | 5 min | Frees up 0.5 mm budget for the grub-screw advance, supports up to 2 mm channel spacers. Issue H1. |
| R2 | Add lead-in chamfer to grub-screw nose | RFQ + drawing notation | n/a (off-the-shelf grub screws with cup point have this) | Specify "cup point" grub screw in RFQ; currently the model says nothing about tip geometry |
| R3 | Tighten left-face tap depth tolerance to ±0.05 mm | GRM-03 drawing | 30 min | Issue L1 — captive bearing axial play budget |
| R4 | Specify finish more explicitly: "Ra 1.6 on knurled features, Ra 3.2 elsewhere; as-machined acceptable on internal bores" | Notes block on each drawing | 1 hr | Karpas guidance |

### Worth quoting both ways

| # | Change | Effort | Rationale |
|---|---|---|---|
| R5 | Working face convexity rounded to R8 (or R10) instead of R8.11 | drawing + spec change | 30 min | Standard tool radius; aesthetic difference invisible to the user |
| R6 | Push rod Ø4.8 instead of Ø4.5 (in same Ø5 bore) | RFQ change | 5 min | Issue M3 — cuts rod slop by 2.5× |
| R7 | Shank depth 11 → 12 mm | `parameters.py` + drawings + spec | 2 hrs | Issue M4 + edge case on wall under bore |

### Worth a phone call to Karpas before settling

| # | Topic | Reason |
|---|---|---|
| R8 | Shank setup count — can they do it in 3? | Single biggest cost driver |
| R9 | Working face convexity — quote with R8.11 specified, then with "R8 or nearest std" as alternate | Cost vs aesthetic |
| R10 | Knurling availability and additional cost | Not covered in their guide; surprise on quote possible |
| R11 | Material grade — confirm CZ121 vs C36000 vs CW508L stock availability | Equivalent for purposes but stock-on-hand matters for lead time |

### Architecture-level (next major revision, NOT for this quote)

| # | Change | Trade |
|---|---|---|
| R12 | H7/g6 → H7/h6 on the shaft/crossbore pair | Tighter fit, less cocking, but slightly higher cost per shop tolerance class |
| R13 | Lengthen shank.width 13.55 → 16 mm | More bore guidance for shaft, lower angular cocking, more material |
| R14 | Consider an O-ring or wave-spring at the captive bearing | Eliminates axial-play sensitivity to manufacturing tolerance |

---

## 10. Items where the design is unambiguously *good*

Worth noting explicitly so they don't get tweaked accidentally:

- **The captive bearing mechanism with the pydantic validator** is excellent engineering hygiene. Don't refactor.
- **The decision to centre the drive screw thread in the shank** (full bore engagement at neutral, ~5+ mm engagement at extremes) is well-thought-out. The 18 mm length matches what the original tool uses; the maker confirmed this by measurement (an earlier model run with a misread 45 mm shaft length had inflated the screw to 28 mm — corrected on the v0.1.4 line).
- **The end-slot tenon on the drive plate** (vs a D-shaped clearance hole or a flat) is mechanically sound and uses standard milling features.
- **The retainer is now the right size** (post-v0.1.2 fix). The waist-Z constraint of 6.24 mm minimum is in the parameter description for future-proofing.
- **The depth-lock bolt collar + collar bore** as anti-cocking guide is a small but smart addition over a plain threaded plug.
- **The shank top dome at R30** is functional + aesthetic + machinable in one ball-nose pass. Don't simplify it.

---

## 11. Test coverage of these findings

What's in `tests/test_geometry.py` already covers:

- ✅ Crossbore + tapped-bore don't merge (`test_shank_bores_dont_overlap_each_other`)
- ✅ Shaft slot is in bounds (`test_shaft_slot_at_outboard_end`)
- ✅ Shaft flat doesn't bisect (`test_shaft_flat_does_not_meet_top`)
- ✅ Captive bearing axial play exists (`test_captive_bearing_axial_play`)
- ✅ Shaft fits crossbore (`test_shaft_fits_through_crossbore`)
- ✅ Blade tip projects below slot (`test_blade_tip_projects_below_shaft_slot`)
- ✅ Drive screw reaches the tap (`test_drive_screw_engages_shank_tap`)
- ✅ Interference: retainer-in-slot, blade-in-slot, tenon-in-slot, shaft-through-crossbore

Worth adding (low effort):

- `test_grub_screw_advance_budget` — assert `slot_spare - spacer.thickness > 0.2` so the channel width can't be configured to leave less than 0.2 mm of grub-screw nose room
- `test_thread_engagement_min` — assert every thread engagement ≥ 1.5 × thread diameter
- `test_push_rod_radial_clearance_in_band` — assert rod is between 0.05 and 0.15 mm radial of the bore (tight without binding)

---

End of review.

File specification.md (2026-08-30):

# Purfling Cutter — Design Specification

**For:** CAD draftsman producing a fully-dimensioned parametric 3D model for CNC quotation
**Status:** Draft — measurements to be added (marked `[TBM]` throughout)
**Units:** Metric (mm). Original tool is likely imperial; convert and round to sensible metric values.
**Reference:** see `diagram.svg` / `diagram.png` for part naming and the Z/X/Y axes.

---

## 1. Purpose and design intent

A **double-blade purfling cutter** used in violin-family lutherie. The luthier presses the working face of the tool against the edge of an instrument plate and draws it around the perimeter. Two parallel **blades** simultaneously score two knife lines into the wood; the waste between is later chiselled out to form the channel into which the decorative purfling strip is glued.

The tool offers **three independent adjustments**:

| Adjustment | Sets | Set by | Locked by |
|---|---|---|---|
| **Blade spacing** | Width of the purfling channel | Choice and order of blades + spacer in the blade slot | Grub screw |
| **Blade projection** | Depth of cut into the plate | Vertical position of blades in the slot before tightening | Grub screw (same one) |
| **Edge margin** | Distance from plate edge to the cut lines | Thumbwheel (fine feed via drive screw) | Depth-lock knob (long bolt up inside shank) |

**Three features distinguish this tool from typical purfling cutters:**

1. **Fine-feed edge margin via integral thumbwheel + drive screw.** Turning the thumbwheel rotates a screw that runs in a tapped bore in the shank, parallel to and just above the shaft. The screw pulls the shaft along via a vertical drive plate. This gives smooth, repeatable adjustment instead of slide-and-clamp.

2. **Captive bearing made from two pieces only.** Reading from outboard inward, the order at the top of the shank is: captive-screw head → drive plate → small axial-play gap → thumbwheel → drive screw → shank. The captive screw threads rightward through a clearance hole in the drive plate and into a tapped hole on the left end face of the thumbwheel. It is deliberately over-length: it bottoms on the tap *before* its head clamps the drive plate. The plate therefore floats free in axial play between the captive-screw head (on its outboard face) and the thumbwheel's left end face (on its inboard face). No thrust washer, no shoulder, no circlip — just a deliberately over-length screw and a clearance hole.

3. **Convex working face with relief slot.** The face that bears on the plate edge is not flat. It carries a vertical relief slot down its full length, leaving two narrow contact corners that act as a two-point fence. This self-corrects against the violin's irregular edge and resists rocking.

These three features are the reason for the commission. The CAD model must preserve them.

---

## 2. Axes and naming convention

See accompanying diagram. These names are canonical — please use them in the CAD part tree and in any correspondence.

**Axes** (right-handed, Z-up convention matching how the tool is held):

- **Z** — along the shank (vertical in normal use). +Z = top of shank (drive-screw end); Z = 0 = bottom (depth-lock-knob end). Blades cut in −Z direction (downward into the violin top surface). The shank length is along Z.
- **X** — along the shaft AND normal to the working face. The shaft cross-bore and the shank tapped bore both run along X and pass *through* the working face — the working face is the +X face of the shank. +X points toward the workpiece. Edge-margin adjustment translates the shaft along X.
- **Y** — perpendicular to both. The tool-travel direction in use (along the violin's edge perimeter at the contact point). The relief slot's width is in Y (across the working face); the slot's length is along Z.

**Parts:**

| Name | Description |
|---|---|
| **Shank** | Square-section brass body. Spine of the tool. Doubles as the fence. |
| **Working face** | Right-hand long face of the shank. Convex profile (~R 8 mm, ≈2 mm sagitta over the depth chord) with a vertical relief slot. Slot runs from the bottom of the shank up to the shaft cross-bore only — it does **not** continue above the shaft. |
| **Top dome** | The +Z end of the shank (where the drive screw sits) is rounded into a spherical dome of similar radius to the working face. Bottom end (where the depth-lock knob sits) is flat. |
| **Contact corners** | Two narrow strips of the working face, one each side of the relief slot. The actual bearing surfaces on the workpiece. |
| **Relief slot** | Vertical slot down the centre of the working face. Runs from the bottom of the shank up to (but not above) the shaft cross-bore. |
| **Shaft cross-bore** | Plain horizontal through-hole near the top of the shank. Sliding fit on the shaft. |
| **Shank tapped bore** | Tapped horizontal through-hole, directly above and parallel to the shaft cross-bore. Carries the drive screw. Tapped along the full X length of the shank. |
| **Depth-lock blind bore** | Long vertical bore running up inside the shank from the bottom, opening into the shaft cross-bore at the top. **Only the lower portion is tapped** (for the depth-lock bolt); above the tapped section is a smooth bore that holds the push rod. |
| **Depth-lock push rod** | Steel rod (⌀4.5 in a ⌀5 smooth bore — sliding fit with ~0.25 mm radial clearance) sitting in the smooth (upper) section of the depth-lock blind bore. Its lower end is pushed up by the depth-lock bolt; its upper end bears on the underside of the shaft to lock it. **Missing from earlier drafts of this spec.** |
| **Shaft** | Brass bar passing horizontally through the shaft cross-bore. Carries the blades at its right end. Translates in X to set edge margin. |
| **Blade slot** | Vertical through-slot in the right end of the shaft. Open top and bottom (blades drop through). Wide enough to hold two blades plus a spacer side by side. |
| **Shaft end tap** | Tapped hole in the right end face of the shaft, along the shaft axis. Receives the grub screw. |
| **Grub screw** | Steel screw threaded into the shaft end tap from the right. Its inner end pushes the blade stack horizontally against the left wall of the blade slot, clamping blades and spacer together. |
| **Blades** | Two flat tool-steel blades. Replaceable. See §5 on blade strategy. |
| **Spacer** | Thin brass or steel shim between the two blades, setting the purfling channel width. Replaceable; different spacers give different channel widths. |
| **Drive plate** | Brass **egg-shaped** plate standing vertically up from the **outboard (left) end** of the shaft. Two circular bosses (larger at the shaft end, smaller at the thumbwheel end) joined by external tangent lines. The plate is fixed to the shaft by **a single central mount screw** plus an **anti-rotation tenon** on the back face that engages a matching slot in the shaft's −X end face. Has a captive-screw clearance hole near its thumb end. **Sits outboard of the thumbwheel.** |
| **Thumbwheel** | Knurled disc **sitting between the drive plate (outboard) and the shank (inboard)**, on the left end of the drive screw. **Integral with the drive screw** — turned from one piece (or permanently joined). |
| **Drive screw** | Threaded shaft extending right (inboard) from the thumbwheel into the shank tapped bore. The thumbwheel's left end face carries a tapped hole along the drive-screw axis for the captive screw. |
| **Captive screw** | Small screw passing rightward from outboard through the drive plate's clearance hole, across a small axial-play gap, and threading into the tap on the thumbwheel's left end face. **Deliberately over-length** so it bottoms on the tap, leaving the drive plate floating in axial play between its head (outboard) and the thumbwheel's left face (inboard). |
| **Depth-lock bolt** | M6 bolt threaded into the depth-lock blind bore's tapped section. Stack from the bottom up: knurled knob (with 1.5 mm chamfer on its bottom edge for hand feel) → unthreaded ⌀6.25 **anti-cocking collar** (mates with an enlarged section at the bottom of the bore) → M6 thread → 1.0 × 45° lead-in chamfer at the tip. Its upper end pushes the depth-lock push rod; the rod (not the bolt) is what bears on the underside of the shaft. |
| **Depth-lock knob** | Knurled knob at the bottom of the shank, integral with the depth-lock bolt. |

---

## 3. Mechanism summary

For the draftsman, so the CAD assembly mates are physically correct.

**Setting edge margin.** Turning the thumbwheel rotates the integral thumbwheel + drive screw assembly. The drive screw runs in the shank tapped bore, so its rotation translates it in X relative to the shank. The thumbwheel translates with it. The drive plate (mounted to the outboard end of the shaft) is captured on the captive screw between the screw's head (outboard side of plate) and the thumbwheel's left end face (inboard side of plate), with a deliberate tiny axial play so the plate doesn't bind. As the thumbwheel-and-drive-screw assembly translates in X, the drive plate is dragged along with it, and the shaft follows. The thumbwheel, drive screw, and captive screw all rotate together; the drive plate and shaft translate without rotating.

**Locking the setting.** The depth-lock knob, at the bottom of the shank, is on the end of an M6 bolt that engages the **lower (tapped) section** of the depth-lock blind bore. Above the tapped section the bore is smooth and contains a steel push rod. Tightening the knob advances the bolt up; the bolt's tip pushes the push rod; the push rod's upper end bears on the underside of the shaft (which crosses through the upper part of the shank). This pinches the shaft against the upper wall of the shaft cross-bore and locks it in X. The push rod is a separate intermediary part — earlier drafts of this spec incorrectly described the bolt itself as bearing on the shaft.

**Setting blade spacing and projection.** With the grub screw loose, blades can be dropped into the blade slot from above and fall straight through (top and bottom of the slot are open). The luthier positions: blade — spacer — blade in the slot, sets the vertical position to give the desired blade projection (depth of cut), and tightens the grub screw. The grub screw threads into the shaft end tap from the right; its inner end advances along the shaft axis and pushes the rightmost blade leftward. This pinches the whole stack — blade, spacer, blade — against the left wall of the blade slot. Blade spacing equals the spacer thickness.

**Using the tool.** Working face of the shank rides on the plate edge; the two contact corners bear, the relief slot clears burrs and irregularities. The tool is drawn along the edge (Y direction). Both blades cut simultaneously.

---

## 4. Driving dimensions and the parametric chain

The CAD model should be built **parametrically**: the dimensions in §4.1 drive everything else. Wall-thickness rules in later tiers depend on those. Changing a driving parameter (e.g. blade thickness if a different blade supply is found) must propagate cleanly through the model.

Each tier table below names the dimension by its full **field path** (`blade.thickness`, `shank.length`, etc.), replacing the original short symbols (`t_b`, `L_shank`). A few fields are owned by mate classes that span multiple parts (e.g. `captive_bearing.axial_play`) — noted in the relevant rows.

### 4.1 Tier 1 — Blades and spacer (decide first)

| # | Parameter | Code field | Value | Notes |
|---|---|---|---|---|
| 1 | Blade thickness | `blade.thickness` | `[TBM]` (likely 0.6–1.0 mm) | Across the wide flat. The face the grub screw pushes against. |
| 2 | Blade width | `blade.width` | `[TBM]` (likely 4–6 mm) | The Y dimension of the blade, sitting in the slot. |
| 3 | Blade length | `blade.length` | `[TBM]` (likely 18–28 mm) | Total length, including ground tip. Must be long enough that the blade can fall fully into the slot AND extend below for the cut. |
| 4 | Blade bevel | `blade.bevel_angle` | `[TBM]` | Single bevel; angle and side. |
| 5 | Spacer thickness range | `spacer.thickness` | `[TBM]` (target 1.0–3.0 mm in 0.2 mm steps) | Sets purfling channel width. Multiple spacers will be supplied. |
| 6 | Spacer height (Y) | `spacer.height` | Slightly less than `blade.width` | So the blades protrude below the spacer when set deep. `[TBM]` |
| 7 | Total clamped stack thickness | `stack_thickness` (derived) | `= 2 × blade.thickness + spacer.thickness` | Range determines blade slot width. |

### 4.2 Tier 2 — Shaft (driven by Tier 1 + wall-thickness rules)

| # | Parameter | Code field | Value rule | Notes |
|---|---|---|---|---|
| 8 | Blade slot width (X) | `shaft.blade_slot_width` | `≥ max(stack_thickness) + grub_screw.max_nose_advance + clearance` | Must fit the widest expected stack plus enough room for the grub screw to advance and clamp. |
| 9 | Blade slot length (Y) | `shaft.blade_slot_length` | `≥ blade.width + clearance` | Just larger than blade width so blades sit cleanly. |
| 10 | Blade slot vertical extent | (through) | Open top and bottom | Blades fall freely through the shaft. Critical: the slot must NOT have a closed bottom. |
| 11 | Shaft cross-section | `shaft.cross_section` | Round | Recommended round; rotation of the shaft is prevented by the drive plate's screw connection and (if needed) by the depth lock bearing on a flat — see open question Q3. |
| 12 | Shaft OD | `params.shaft_outer_diameter` (computed at top level from `cutting_pair.nominal_diameter`) | Round to nearest 0.5 mm. | Owned by the shaft↔crossbore mating pair, not by ShaftParams alone — the crossbore tracks it via the same `cutting_pair`. |
| 13 | Wall thickness around blade slot | `shaft_wall_around_slot` (derived) | `= min((OD − slot_width)/2, (OD − slot_length)/2)`; rule: `≥ 2 mm`, `≥ 1.5 × blade.thickness` | **Critical constraint.** Derived from shaft OD and slot dimensions; spec rule enforced by validator. |
| 14 | ~~Wall thickness around shaft end tap~~ | — | **Rule removed.** | After measuring the original, the grub-screw tap goes all the way to the blade slot — no wall in between. Tap depth = `shaft.end_to_slot_distance` and the grub-screw tip emerges directly into the slot. The wall-thickness validator for this rule has been removed in the code. |
| 15 | Grub screw thread | `grub_screw.thread` | M3 or M4 `[TBM]` | Specify before sizing shaft end. |
| 16 | Grub screw nose protrusion (max) | `grub_screw.max_nose_advance` | `≥ shaft.blade_slot_width − min(stack_thickness)` | Grub screw must be able to reach the thinnest stack and clamp it. |
| 17 | Distance from shaft right-end face to blade slot | `shaft.end_to_slot_distance` | `[TBM]` | Determines how much wall is between shaft end tap and blade slot. See item 14. |
| 18 | Shaft total length | `shaft.length` | `[TBM]` | Must support: blade slot at right end + protrusion through shank during full X travel + length to clear thumbwheel + axial gap + drive plate at outboard (left) end. |
| 19 | Drive plate mounting on shaft | `shaft.drive_plate_mount_thread` + `shaft.drive_plate_mount_depth` (slot geometry derived from `drive_plate.tenon_depth/height` in `gramil/parts/shaft.py`) | **Single** central tapped hole (M2) on the outboard end face + a **slot** across the same face that receives the drive plate's tenon | Replaces the original soldered joint. The central screw holds axially; the slot–tenon pair prevents rotation. The slot is milled across the full diameter (one mill pass); its dimensions match the plate tenon. |

### 4.3 Tier 3 — Shank (driven by Tier 2 + wall-thickness rules)

| # | Parameter | Code field | Value rule | Notes |
|---|---|---|---|---|
| 20 | Shaft cross-bore diameter | `shank.crossbore_diameter` | `shaft.outer_diameter + sliding-fit allowance` | **Precision fit.** H7/g6 or equivalent (≈ 0.02–0.04 mm clearance). |
| 21 | Shank tapped bore | `drive_screw.thread` | **M3 × 0.5 (standard coarse)** | Cut and gauged with standard M3 taps/dies; must mate with standard M3 hardware. NB: M3 × 0.5 *is* the coarse pitch — do not read "fine" and cut M3 × 0.35. |
| 22 | Centre-to-centre distance between shank tapped bore and shaft cross-bore | `shank.crossbore_to_tapped_bore_gap` | `[TBM]` | Must be large enough that wall between the two bores (≥ 1.5 × thread major radius, item 23) is preserved. |
| 23 | Wall thickness between shank tapped bore and shaft cross-bore | `shank_wall_between_bores` (derived) | `= gap − crossbore_radius − tapped_drill_radius`; rule: `≥ 1.0 × thread major radius`, `≥ 1.2 mm` | **Critical constraint.** Wall rule relaxed after measuring the original (was `≥ 1.5 × radius`, `≥ 2 mm`). |
| 24 | Wall thickness around shaft cross-bore (other directions) | `shank_wall_around_crossbore` (derived) | `= min(crossbore_x − crossbore_radius, depth/2 − crossbore_radius)`; rule: `≥ 0.15 × D_xb`, `≥ 1 mm` | **Critical constraint.** Wall rule relaxed after measuring the original tool (was `≥ 0.6 × D_xb`, `≥ 3 mm` — those values were a CAD-shop guess; the real brass tool runs much closer to 0.15× the bore diameter). Bore axis is along X; walls measured in Z (toward bottom of shank) and Y (top and bottom of cross-section). Assumes bore centred in Y. |
| 25 | Wall thickness around shank tapped bore (other directions) | `shank_wall_around_tapped_bore` (derived) | `= min(pos_tb − tap_drill_radius, depth/2 − tap_drill_radius)`; rule: `≥ 1.0 × thread major radius`, `≥ 1 mm` | **Critical constraint.** Wall rule relaxed (was `≥ 1.5 × radius`, `≥ 3 mm`). |
| 26 | Shank cross-section | `shank.width` × `shank.depth` (X × Y) | Square (or near-square rectangular) | `width` is depth-from-working-face into the body (X direction); `depth` is the cross-section dimension perpendicular to both the shank length and the shaft (Y direction). Must satisfy items 23, 24, 25. |
| 27 | Shank length (Z) | `shank.length` | `[TBM]` (likely 90–110 mm) | Affects balance, reach, and the length of the depth-lock blind bore. |
| 28 | Shank cross-bore position (from top of shank) | `shank.crossbore_position_from_top` | `[TBM]` | Near the top. Sets how high the mechanism sits relative to the working face. |
| 29 | Shank tapped bore position | `shank.tapped_bore_position_from_top` | `= shank.crossbore_position_from_top − shank.crossbore_to_tapped_bore_gap` | Derived; sits above the shaft cross-bore. |
| 30 | Depth-lock blind bore diameter (tap + push-rod section) | `shank.depth_lock_bore_diameter` | 5.0 mm (M6 tap drill) | Same drill is used for both the M6-tapped section and the smooth section above it. The ⌀4.5 push rod (item 32a) slides in the smooth section with ~0.25 mm radial clearance. |
| 30a | Depth-lock collar bore diameter | `shank.depth_lock_collar_bore_diameter` | 6.35 mm | Enlarged section at the **bottom** of the depth-lock bore that receives the bolt's ⌀6.25 anti-cocking collar (item 32c). 0.05 mm radial clearance — light sliding fit. |
| 30b | Depth-lock collar bore length | `shank.depth_lock_collar_bore_length` | 5.5 mm (= bolt collar length + 0.5) | Slightly longer than the bolt collar so manufacturing tolerance can't land the collar's top against the tap shoulder. |
| 30c | Depth-lock bore threaded length | `shank.depth_lock_threaded_length` | `[TBM]` (ESTIMATE: 12 mm) | M6-tapped section sits between the collar bore (bottom) and the smooth push-rod section (top). |
| 31 | Depth-lock blind bore depth | `shank.depth_lock_bore_depth` (derived) | `= shank.length − shank.crossbore_position_from_top` | Bore extends from the bottom of the shank up to and into the shaft cross-bore — the push rod must reach the cross-bore region to bear on the shaft. (Earlier draft of this spec called for a `small_clearance` below the cross-bore; that was wrong.) |
| 32 | Depth-lock thread | `depth_lock.thread` | M6 measured | Hand-clamped, not metered. |
| 32a | Push-rod diameter | `depth_lock.push_rod_diameter` | 4.5 mm | ⌀4.5 in ⌀5 bore = 0.25 mm radial sliding clearance. Validator enforces rod < bore. |
| 32b | Push-rod length | `depth_lock.push_rod_length` | 45 mm | Reaches from the bolt tip (at the top of the tap, lock position) up to the shaft underside. |
| 32c | Bolt collar diameter | `depth_lock.bolt_collar_diameter` | 6.25 mm | Unthreaded section between the knob and the M6 thread. Acts as an anti-cocking guide when seated in the collar bore (item 30a). |
| 32d | Bolt collar length | `depth_lock.bolt_collar_length` | 5 mm | Bore (item 30b) is 0.5 mm longer for tolerance. |
| 32e | Bolt thread length | `depth_lock.bolt_thread_length` | 13 mm | Sized so the system has 1 mm of preload margin at the rod-lock position (knob clears the shank bottom by 1 mm). |
| 32f | Bolt tip lead-in chamfer | `depth_lock.bolt_tip_chamfer` | 1.0 × 45° | One full M6 thread pitch — visible lead-in that prevents cross-threading. |
| 32g | Knob bottom chamfer | `depth_lock.knob_bottom_chamfer` | 1.5 × 45° | Hand-facing edge; bevels the otherwise-sharp circumference for grip comfort. |
| 33 | Relief slot width (Y) | `shank.relief_slot_width` | `[TBM]` (likely 2–8 mm) | Wide enough to clear edge irregularities; narrow enough to keep contact corners close. Measured *across* the working face, perpendicular to slot length. |
| 34 | Relief slot depth (X) | `shank.relief_slot_depth` | ~1 mm | Depth into the body from the working face. Just enough to guarantee no contact in slot region. |
| 34a | Relief slot length (Z) | `relief_slot_length` (derived) | `= shank.length − shank.crossbore_position_from_top` | Slot runs from the bottom of the shank up to the shaft cross-bore. Does *not* extend above the shaft (corrected from earlier drafts that said "full length of the shank"). |
| 35 | Working face convexity radius | `shank.working_face_radius` (derived) | Derived from the measured sagitta/chord: `R = (c² + 4s²) / (8s)` | Earlier spec drafts described this as a "large radius". Measurement gives R ≈ 8 mm on the original — far smaller than implied; the spec was wrong. |
| 35a | Top dome radius | `shank.top_dome_radius` | Similar to working face radius | Spherical dome at the +Z end (top, next to the drive screw). Bottom end (−Z, next to the depth-lock knob) is flat. |
| 35b | Edge fillet radius | `shank.edge_fillet_radius` | ~0.5 mm | Ergonomic finishing layer, not previously specified in §4. Applied to every external edge of the shank. |
| 36 | Contact corner width (Y) | `shank.contact_corner_width` (derived) | `= (shank.depth − shank.relief_slot_width) / 2` | Symmetric. Contact corners sit either side of the relief slot, measured in Y across the working face. |

### 4.4 Tier 4 — Drive train

| # | Parameter | Code field | Value rule | Notes |
|---|---|---|---|---|
| 37 | Drive screw thread | `drive_screw.thread` | Matches item 21 | |
| 38 | Drive screw thread pitch | `drive_screw.thread_pitch` | ≈ 0.5 mm (user estimates 2 turns/mm) | Sets adjustment resolution. |
| 39 | Drive screw length | `drive_screw.length` | `[TBM]` | Must support full X travel of shaft + adequate engagement at minimum-margin setting. |
| 40 | Drive screw left-end tap | `drive_screw.left_face_tap` | For captive screw; M2 or M2.5 `[TBM]` | Bottomed by the captive screw — see Tier 5. Depth: `drive_screw.left_face_tap_depth`. |
| 41 | Thumbwheel diameter | `thumbwheel.diameter` | `[TBM]` (likely 15–22 mm) | Big enough for fingertip torque; small enough not to foul the work. |
| 42 | Thumbwheel thickness | `thumbwheel.thickness` | `[TBM]` | |
| 43 | Thumbwheel knurl | `thumbwheel.knurl` | Straight (axial) `[TBM]` | |
| 44 | Drive screw and thumbwheel join | — | **Integral** — one piece, or permanently joined | Must rotate as a unit. |

### 4.5 Tier 5 — Drive plate and captive-screw bearing

Geometry, outboard → inboard along X: captive-screw head → drive plate → axial-play gap → thumbwheel left face → (captive-screw thread engagement inside thumbwheel).

| # | Parameter | Code field | Value rule | Notes |
|---|---|---|---|---|
| 45 | Drive plate outline | — | **Egg shape**: larger circle at the shaft end, smaller circle at the thumbwheel end, joined by external tangent lines. | The plate is not a rectangle. |
| 45a | Drive plate shaft-end boss radius | `drive_plate.shaft_end_radius` | 4 mm (⌀8 — matches shaft OD) | Sized to match the shaft so the plate's bottom edge is flush with the shaft cylinder and the tenon (item 49a) goes edge-to-edge with no overhang. |
| 45b | Drive plate thumb-end boss radius | `drive_plate.thumb_end_radius` | 3 mm (⌀6) | Sized to encircle the captive-screw clearance hole with adequate wall. |
| 45c | Centre-to-centre vertical distance | derived | `= shank.crossbore_to_tapped_bore_gap` | Plate spans from shaft axis up to drive-screw axis. |
| 46 | Drive plate thickness (X) | `drive_plate.thickness` | 3 mm (measured) | Thickness in the axial direction. The plate keeps full thickness through the load-bearing region — the anti-rotation feature is a *tenon* on the back face (item 49a), not a slot through the plate. |
| 47 | Drive plate captive-bearing clearance hole | `drive_plate.captive_clearance_hole_diameter` | 2.6 mm (M2 + ~0.3 mm radial — deliberately sloppy) | At the thumb-end boss. The drive plate rides on the captive screw as a *bearing*, so it needs more clearance than a normal screw hole. |
| 48 | Drive plate mount clearance hole | `drive_plate.mount_hole_diameter` | 2.4 mm (M2 standard clearance) | At the shaft-end boss. The mount screw passes through here into the shaft's central tap (item 19). The hole drills *through* the tenon. |
| 49 | Drive plate position on shaft (Z) | derived | Mounted on the outboard −X end face of the shaft | The shaft must be long enough on its outboard side that the plate sits clear of the thumbwheel. The axial-play gap (item 53) sits between the plate's inboard face and the thumbwheel's outboard end face. |
| 49a | Anti-rotation tenon (plate side) | `drive_plate.tenon_depth` / `tenon_height` | 1.5 mm projection × 3 mm tall × full plate width at Z = 0 | Rectangular boss on the plate's +X back face, centred at the shaft-end boss. Y outline follows the plate's egg perimeter at the tenon's Z range (no protruding corners). Mates with the matching slot in the shaft (item 19). The tenon is on the plate (not the shaft) so the plate keeps full thickness in the load-bearing region. |
| 50 | Captive screw thread | `captive_screw.thread` | Per item 40 | M2 or M2.5 `[TBM]`. |
| 51 | Captive screw useful length (head underside to tip) | `captive_screw.length` *(owned by `captive_bearing`)* | `= drive_plate.thickness + captive_bearing.axial_play + drive_screw.left_face_tap_depth` | **Critical:** the screw must bottom on the tap with `captive_bearing.axial_play` mm of axial clearance remaining between its head and the drive plate. |
| 52 | Captive screw head | `captive_screw.head` | Pan or cheese; larger than `drive_plate.clearance_hole_diameter` | Acts as the retainer. |
| 53 | Axial play | `captive_bearing.axial_play` *(owned by `captive_bearing`)* | 0.1–0.3 mm | The designed bearing clearance. Verify after assembly with feeler gauges. |

This is the *bearing*: captive-screw head + drive plate + thumbwheel left end face form a captive but non-binding interface. The drive plate floats in the axial-play gap; the thumbwheel rotates freely.

---

## 5. Open questions to resolve from the original

In priority order.

1. **Spacer storage / set.** Are spacers loose, or stored on the tool somehow? Are they brass or steel? If a set of different thicknesses is supplied, what are they?

2. **Wall between shaft end tap and blade slot.** How much material is there between the end of the blade slot and the bottom of the shaft end tap? Determines how deep the grub screw can be tapped without breaking through.

3. **Shaft rotation prevention.** Does the original rely solely on the drive plate (single central screw + tenon–slot anti-rotation between plate and shaft) to prevent shaft rotation in the cross-bore, or is there also a flat machined along the shaft for the depth-lock bolt to bear on? Likely just the drive plate, but worth checking. (If there's no flat, the depth-lock push rod bears on the shaft's flat-machined underside, which is what this build models — see `shaft.flat_depth`.)

4. **Drive screw end at the shank tapped bore.** When the tool is at minimum edge margin (shaft pushed all the way toward the work), does the drive screw exit the shank tapped bore on the far side, or just bottom out internally?

5. **Maker's marks** on the original — note location and reproduce or omit as preferred.

---

## 6. Materials

| Component | Material | Notes |
|---|---|---|
| Shank | Free-machining brass (CZ121 / C36000) | Matches original. |
| Shaft | Free-machining brass | Brass to match the original. |
| Drive plate | Brass | Small cosmetic part. |
| Thumbwheel + drive screw (integral) | Brass | Brass to match the original. Knurl finish on thumbwheel. |
| Depth-lock knob + bolt | Brass for knob; steel bolt OR brass throughout | Original is likely brass throughout. Steel bolt with a brass knob silver-soldered on is an alternative. |
| Captive screw | Stainless steel | Any stock M2 pan-head — the role is purely to retain the drive plate. |
| Grub screw | Stainless or hardened steel | Standard part — slotted, socket, or knurled head per original. |
| Drive plate mount screw | Stainless steel | Single M2 pan-head, central. Anti-rotation is via the plate-to-shaft tenon/slot (item 19), not a second screw. |
| Blades | O1 tool steel, hardened and tempered, OR commercial Ibex/Herdim blades | See §7. |
| Spacers | Brass or steel shim stock | Set of sizes. |

---

## 7. Blade strategy (decide before finalising)

No convenient commercial supply of loose purfling blades exists. Three options:

1. **Commercial donor blades.** Buy a complete Ibex or Herdim purfling cutter, measure those blades, spec the new tool around them. Gives a permanent reorderable supply path. **Recommended.**
2. **Bespoke ground blades.** Have a toolmaker grind matching blades from O1 flat stock, hardened and tempered.
3. **Repurposed marking-knife or scalpel blanks.** Cheap and replaceable but non-traditional.

**Action item for the owner:** decide which before the spec goes to the draftsman, then fill in §4.1 with the chosen blade's dimensions.

---

## 8. Tolerances and fits

**Critical fits** (determine cut quality and must be tight):

| Interface | Recommended fit | Reason |
|---|---|---|
| Shaft in shaft cross-bore | H7/g6 (sliding, ≈ 0.02–0.04 mm clearance) | Controls how square the cut stays. |
| Drive screw in shank tapped bore | Standard tapped thread, class 6H/6g | Backlash here = backlash in edge-margin adjustment. |
| Blade slot to blade thickness | Light, hand-fit | The grub screw clamps the slop out. |

**Non-critical clearances** (just need not to bind):

| Interface | Recommended |
|---|---|
| Captive screw in drive plate clearance hole | Generous (0.1–0.3 mm radial) — sloppy is fine |
| Drive plate against thumbwheel end face | Light sliding contact when stationary; rotational clearance via the axial play of the captive screw |
| Drive plate position on shaft | Fixed location, no movement intended |
| Depth-lock bolt in blind bore | Standard thread fit |

General machining tolerance: **±0.05 mm** unless noted otherwise.

---

## 9. Finish

| Surface | Finish |
|---|---|
| All visible brass | Draw-filed and polished to a satin or low-gloss finish. No lacquer (original style). |
| Knurls | Straight (axial) knurl, medium pitch, on thumbwheel and depth-lock knob. |
| Contact corners (working face) | Polished smooth. These bear on the violin's finished edge and must not mark it. |
| Tapped/threaded bores | Standard. |
| Shaft (inside the shank cross-bore) | Smooth, free from burrs. |

---

## 10. Function tests (acceptance criteria)

After manufacture, the tool must:

1. Sit stable on a flat reference edge with both contact corners bearing simultaneously — no rocking.
2. Allow continuous, smooth X travel of the shaft through the full range with the depth-lock knob loose.
3. Allow the depth lock to clamp the shaft firmly with no perceptible X movement under reasonable hand force.
4. Allow the edge-margin thumbwheel to be turned by fingertip force, with one full rotation producing approximately `[TBM]` mm of shaft translation (matching the drive-screw pitch), repeatable to within ±0.05 mm.
5. Drive plate to spin freely on the captive-screw bearing — no binding when the thumbwheel is rotated; no axial slop greater than `[TBM]` mm (target ≤ 0.3 mm).
6. Hold blades square to the shaft axis and parallel to each other to within ±0.1° after grub-screw clamping.
7. Hold blade spacing to within ±0.05 mm of the spacer thickness over a representative cut (full perimeter of a violin top).
8. Cut two clean, parallel lines in figured maple ≥ 0.5 mm deep without blade deflection.

---

## 11. Things explicitly left to the draftsman's / machinist's judgement

- Exact shank cross-section dimensions, provided the wall-thickness rules in §4.3 are met.
- Exact thumbwheel and depth-lock-knob diameters and knurl detail, provided they match the original's visual style.
- Internal radii and chamfers, provided no sharp internal corners are left in stressed areas.
- Whether the depth-lock bolt's tip is flat, cone, or cup point — designer's choice, provided it grips reliably and does not mark the shaft excessively over many cycles.
- Surface texture beyond §9.

---

## 12. Deliverables

1. Fully parametric 3D CAD model with the part tree using §2 names.
2. 2D drawings of each part with dimensions and tolerances suitable for CNC quotation.
3. Assembly drawing showing the three independent adjustments.
4. STEP and native CAD files.
5. Bill of materials.

---

*End of specification. Items marked `[TBM]` to be filled in after measurement of the original tool — see `measurement-checklist.md`.*

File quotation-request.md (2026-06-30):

# RFQ: CNC Machining of Brass Violin Purfling Cutter

Customer: Paul Fremantle
Email: paul@fremantle.org
Date: 30 June 2026

## Overview

I am seeking quotations for CNC machining of a small precision hand tool used by violin makers.

Each set consists of:

- Five machined brass parts (GRM-01 to GRM-05)
- Four copper blade retainers (GRM-06)
- Two hardened tool-steel blades (GRM-07)
- One mild-steel push rod (cut to length, non-precision)

Please quote for the following quantities:

- 1 set
- 20 sets
- 50 sets

The tool is assembled from the supplied parts; an assembly drawing and individual part drawings are included.

---

## Parts Included in Each Set

| Drawing | Description | Material | Qty / set |
|---|---|---|---|
| GRM-01 | Shank | Brass — H62 (CuZn40) | 1 |
| GRM-02 | Shaft | Brass — H62 (CuZn40) | 1 |
| GRM-03 | Thumbwheel with integral drive screw | Brass — H62 (CuZn40) | 1 |
| GRM-04 | Drive plate | Brass — H62 (CuZn40) | 1 |
| GRM-05 | Depth-lock bolt with knurled knob | Brass — H62 (CuZn40) | 1 |
| GRM-06 | Bone-shaped blade retainer | Copper sheet (annealed) | 4 |
| GRM-07 | Blade | O1 tool steel, hardened ~60 HRC | 2 |
| — | Ø4.5 × ~46.6 mm steel push rod (cut to length, no tolerance — see notes) | Mild steel, bright-drawn | 1 |

**Brass grade:** originally specified as free-cutting brass (CZ121 / C36000); **H62 (CuZn40)** substituted — sourced by the shop and accepted.

---

## Critical Requirements

- Shaft and shank bore to provide a smooth sliding fit (nominal Ø8 H7/g6)
- All threads to drawing
- **M3 × 0.5 drive-screw thread — CRITICAL (this is the tool's adjustment mechanism).** Cut the external thread on GRM-03 (drive screw) and the internal thread in the GRM-01 shank bore with **standard M3 × 0.5 tap and die** — NOT M3 fine (0.35). The two must run together smoothly along the full length; please gauge / trial-fit this pair specifically.
- Straight knurl, 0.8 mm pitch, on GRM-03 and GRM-05
- Parts fully deburred
- Visible brass surfaces finished to a clean satin appearance
- Trial assembly to confirm fit of mating components

---

## Files Supplied

- Assembly drawing with BOM
- PDF drawings for each part
- STEP files for all machined components

---

## Requested Quote Format

Please provide:

- Unit price for each quantity tier (1, 20, and 50 sets)
- Lead time
- Shipping cost to the UK
- Any recommended design changes to reduce manufacturing cost

---

## Notes

If any feature appears unnecessarily expensive to manufacture, I would welcome suggestions for simplifying the design before production.

---

## Notes on the non-brass parts (GRM-06, GRM-07, push rod)

### GRM-06 Bone-shaped copper blade retainer (4 per tool)

Custom shape — small bone-shaped flat sheet that fits in the shaft's blade slot, two on each side of the blade-stack, locking the stack against the open ±Z direction of the slot.

| Item | Spec |
|---|---|
| Material | Copper (annealed sheet stock) |
| Outline | Bone shape: 10 mm long (Z) — 6.25 mm waist between 1.875 mm end blocks — 0.85 mm thick (X), Y width 5.5 mm at the ends tapering to 4.3 mm in the middle. Outer knob corners R1.3 fillet; inner shoulder corners R0.5 fillet. See GRM-06 drawing. |
| Tolerance | ±0.05 mm on thickness; outline ±0.1 mm |
| Finish | Deburred. As-received sheet finish is fine. |
| Process suggestion | Laser cut or stamp from copper sheet — both work; whichever is cheaper at your volumes. |

### GRM-07 Blade (2 per tool)

| Item | Spec |
|---|---|
| Material | O1 tool steel (or equivalent high-carbon), hardened and tempered to ~60 HRC |
| Thickness | 0.7 mm |
| Width | 3.6 mm |
| Length | 23 mm |
| Bevel | Single, 25°, ground at the tip; primary grind + hone by the luthier after delivery |
| Tip | Round, polished |

### Push rod

Ø4.5 mm bright-drawn mild steel, **cut to ~46.6 mm**. Plain column, not a
precision part — **no length tolerance required**, but please **err long: do
not cut below 45.6 mm** (too short and it can't reach to clamp; a little over
just leaves the lock knob slightly proud, which is fine).

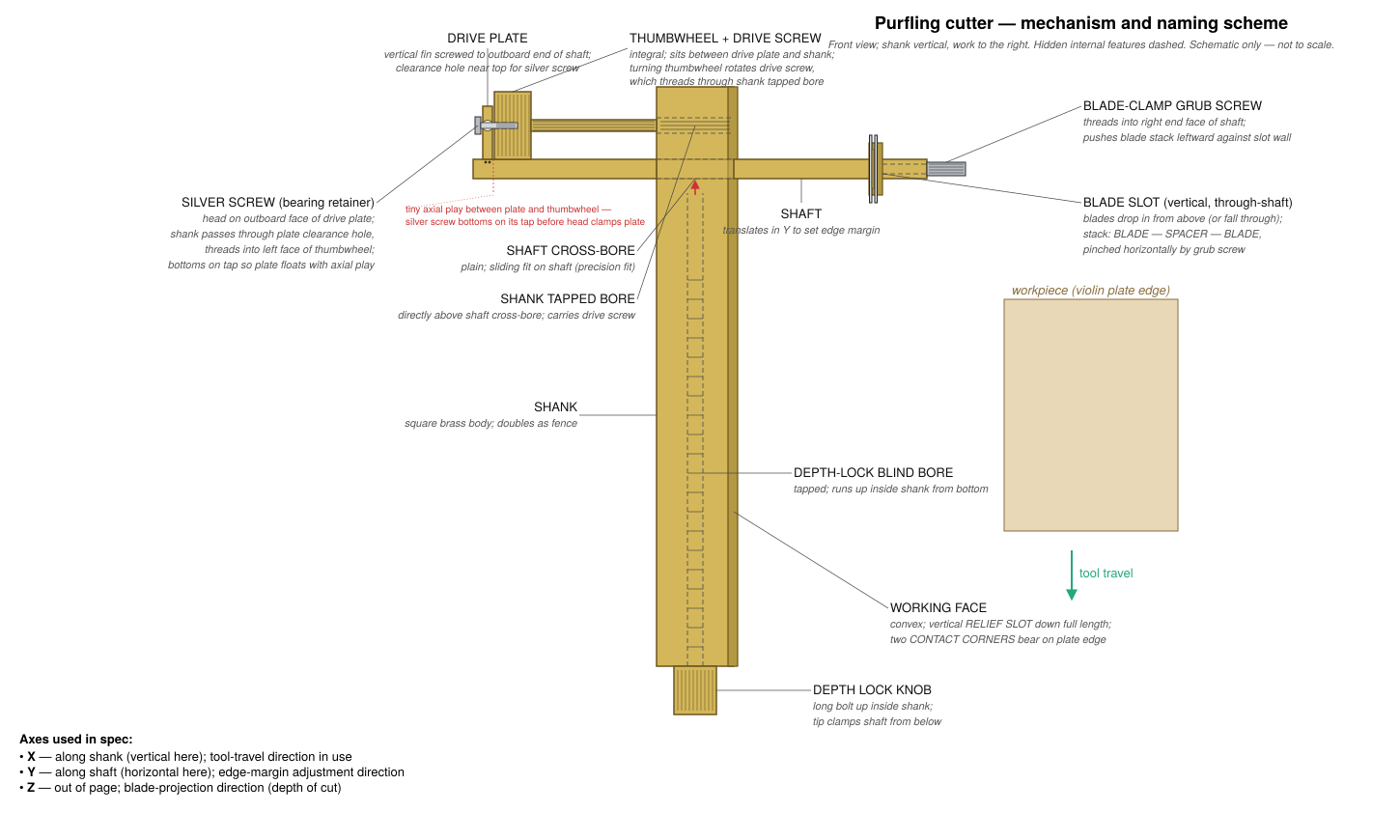
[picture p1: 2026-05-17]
diagram.png

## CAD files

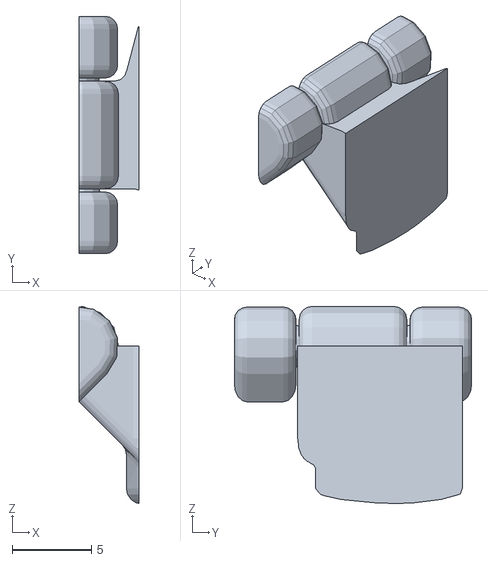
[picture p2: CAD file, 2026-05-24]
gramil/case/hinge_stls/reference_hinge_base.stl
3.81 x 15.0 x 12.5

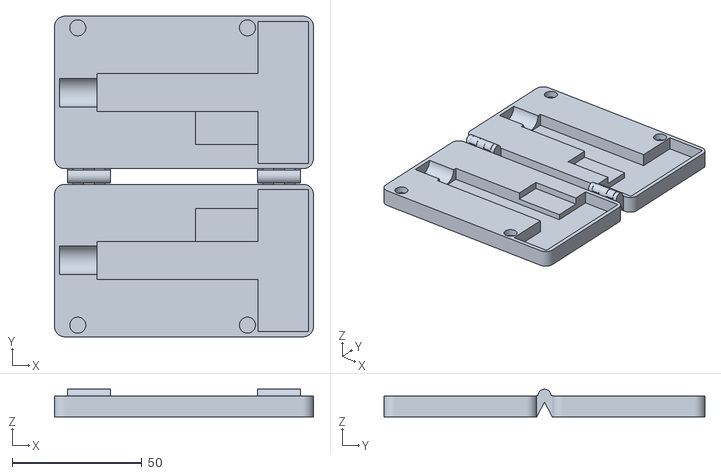
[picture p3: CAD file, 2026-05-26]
gramil/case/printable/case_print_in_place.stl
100.0 x 123.8 x 10.7

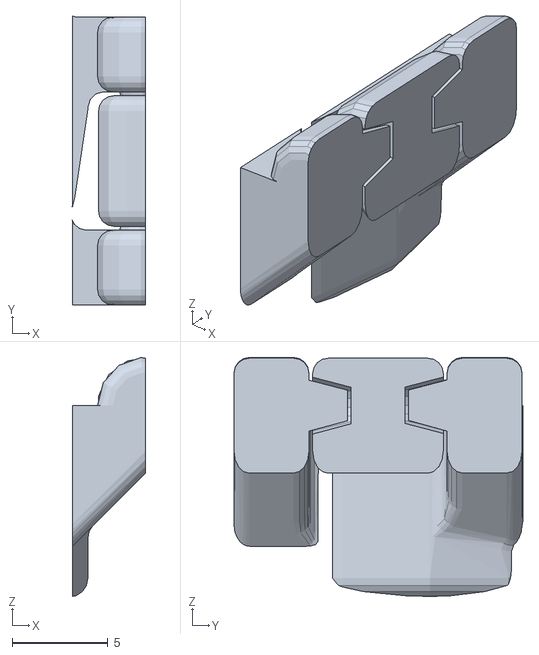
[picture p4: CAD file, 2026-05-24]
gramil/case/hinge_stls/reference_hinge_lid.stl
3.81 x 15.1 x 12.5

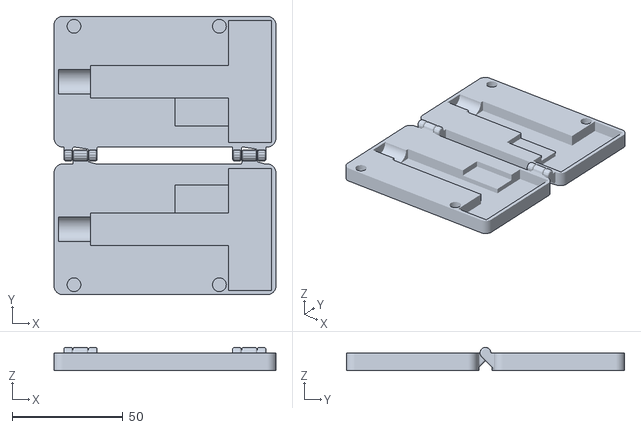
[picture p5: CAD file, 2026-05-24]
gramil/case/printable/case_print_in_place_oralb.stl
100.0 x 125.4 x 10.5

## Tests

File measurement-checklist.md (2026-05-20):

# Measurement checklist — original purfling cutter

**Purpose:** capture every dimension marked `[TBM]` in `specification.md`, plus redundant measurements to sanity-check the parametric chain. Work in millimetres throughout.

**Tools:**
- Vernier or digital callipers (resolution 0.01 mm)
- Micrometer if you have one (blade thickness especially)
- Thread pitch gauge OR a set of known fasteners to match against
- Small engineer's square
- Pin gauges or a set of drill shanks (for measuring bores)
- Feeler gauges (for the convexity of the working face and any axial play)
- Camera/phone for the photos called out below
- A sheet of paper and a pencil for stamps and knurl rubbings

**Order matters** — earlier groups are upstream in the parametric chain.

---

## Phase 0 — Photos (before any disassembly)

Take these with a ruler in frame for scale.

- [ ] **P0.1** End view from the blade side, showing the blade slot and how the blades/spacer sit in it. Particularly how the blades are oriented and how the spacer sits relative to them.
- [ ] **P0.2** End view from the thumbwheel side, showing the drive plate, the captive screw head, and the gap (if any) between captive-screw head and drive plate.
- [ ] **P0.3** Top view of the whole assembly.
- [ ] **P0.4** Looking straight down the shaft from the blade end.
- [ ] **P0.5** Working face straight-on, showing the relief slot.
- [ ] **P0.6** End-on view of the working face — i.e. looking at one end of the shank to see the cross-section profile of the working face (convexity).
- [ ] **P0.7** Bottom of the shank, showing the depth-lock knob and how the bolt enters.
- [ ] **P0.8** Any maker's marks, stamps, or numbers — note location.

---

## Phase 1 — Blades and spacer (Tier 1)

If possible, slacken the grub screw and remove the blades and spacer. Mark each so they go back in the same orientation.

- [ ] **M1.1** Blade thickness `t_b` — across the wide flat. Three measurements along the blade; record min/max.
- [ ] **M1.2** Blade width `w_b` — the dimension that sits in the Z direction in the slot.
- [ ] **M1.3** Blade total length `l_b` including ground tip.
- [ ] **M1.4** Bevel — single or double? Bevel angle (estimate). Which side?
- [ ] **M1.5** Tip geometry — straight, angled, or curved? Sketch.
- [ ] **M1.6** Confirm both blades are identical (or note differences).
- [ ] **M1.7** Spacer thickness `t_s`.
- [ ] **M1.8** Spacer width and height — particularly: is the spacer's Z-height *less* than the blade width, so blades protrude below it? Sketch.
- [ ] **M1.9** Spacer material (magnet test: brass/non-ferrous vs steel).
- [ ] **M1.10** Are there other spacers stored on the tool or supplied with it? If yes, list thicknesses.

---

## Phase 2 — Shaft, blade slot, grub screw (Tier 2)

With blades and spacer removed, the slot is accessible.

- [ ] **M2.1** Shaft OD `d_shaft`. Round or has a flat? If a flat, measure its width, length, and angular position relative to the blade slot.
- [ ] **M2.2** Shaft total length `L_shaft`.
- [ ] **M2.3** Blade slot width (Y) `W_slot`.
- [ ] **M2.4** Blade slot length (Z) `L_slot`.
- [ ] **M2.5** Confirm slot passes fully through the shaft top-to-bottom (item 10 of spec).
- [ ] **M2.6** Distance from shaft right-end face to the **right wall** of the blade slot `pos_slot_right`.
- [ ] **M2.7** Distance from shaft right-end face to the **left wall** of the blade slot `pos_slot_left` (= `pos_slot_right + W_slot`).
- [ ] **M2.8** Grub screw thread — gauge or match to standard fasteners.
- [ ] **M2.9** Grub screw total length, head style, drive type (slotted/hex/knurled).
- [ ] **M2.10** Maximum grub-screw nose advance — with the screw fully home (no blades in slot), how far past the right wall of the slot does its nose extend? This tells you the tap depth and clamp range.
- [ ] **M2.11** Drive-plate mounting features on the shaft (left end) — soldered fillet, pinned, or tapped holes? If tapped, thread size, position, count. Sketch and photograph in close-up.

---

## Phase 3 — Shank (Tier 3)

Best done with the shaft removed if it comes out cleanly without forcing.

- [ ] **M3.1** Shank cross-section — width (Y) × depth (Z). Spot-check at top, middle, bottom.
- [ ] **M3.2** Shank total length `L_shank`.
- [ ] **M3.3** Shaft cross-bore diameter `D_xb` — pin gauges or largest drill shank that passes through with slip fit.
- [ ] **M3.4** Position of the shaft cross-bore from the top of the shank `pos_xb`.
- [ ] **M3.5** Shank tapped bore — diameter, position. Run a known thread into it to identify pitch and major diameter.
- [ ] **M3.6** Centre-to-centre distance from shank tapped bore to shaft cross-bore `gap_bores`. **Most easily measured by inserting tight-fitting pins/wires in both bores and measuring between them, then correcting for half each pin's diameter.**
- [ ] **M3.7** Working face profile — truly curved, or flat with chamfered edges? Hold a steel rule across; check for light gap at centre or corners.
- [ ] **M3.8** Convexity height (if curved) — rise at centre vs corners, measured with feeler gauges under a straightedge.
- [ ] **M3.9** Relief slot width (Y), depth (Z), length (X). Does it run full length of the shank?
- [ ] **M3.10** Contact corner width (Y) either side of relief slot. Should be symmetric.
- [ ] **M3.11** Depth-lock blind bore — diameter (from the depth-lock bolt) and depth (insert a thin rod from the bottom with the bolt removed, mark where the rod stops).
- [ ] **M3.12** Depth-lock thread — identify from the bolt itself.

---

## Phase 4 — Drive train (Tier 4)

Remove the captive screw (carefully — it's small) and the drive screw assembly comes free.

- [ ] **M4.1** Drive screw thread — pitch and major diameter. **Critical:** the pitch is the edge-margin resolution.
- [ ] **M4.2** Drive screw total length.
- [ ] **M4.3** Tap on the **left end face of the thumbwheel** — diameter and depth of the tap that the captive screw goes into. Use the captive screw itself to identify thread.
- [ ] **M4.4** Thumbwheel left end-face geometry — flat? Stepped boss with a recessed area for the drive plate to bear on? This is the surface the drive plate floats against on its inboard side.
- [ ] **M4.5** Sanity check on pitch — reassemble enough to turn the thumbwheel 10 full turns, measure shaft translation, divide by 10. Compare to M4.1.
- [ ] **M4.6** Thumbwheel OD and thickness.
- [ ] **M4.7** Thumbwheel knurl style — straight or diamond? Pitch (lines per 5 mm).
- [ ] **M4.8** Confirm thumbwheel + drive screw is integral (one piece) or a joined assembly. Try to wiggle/twist them relative to each other — there should be no movement.

---

## Phase 5 — Drive plate and captive-screw bearing (Tier 5)

- [ ] **M5.1** Drive plate dimensions — height (Z), width (X), thickness (Y).
- [ ] **M5.2** Drive plate clearance hole diameter.
- [ ] **M5.3** Drive plate clearance-hole position — distance from the bottom of the plate (the shaft) to the centre of the clearance hole. **Must equal `gap_bores` from M3.6.** A useful sanity check.
- [ ] **M5.4** Position of drive plate along shaft — the drive plate is mounted on the **outboard (left) end face of the shaft**. Confirm this and measure the distance from the shank's left face to the drive plate's inboard face when the shaft is at its mid-Y-travel position.
- [ ] **M5.5** Captive screw — overall length, thread length, head diameter and thickness, drive type (slotted, etc.).
- [ ] **M5.6** Captive screw tap engagement length when fully home — back the captive screw out a couple of turns, measure the screw's protrusion change. The "bottomed" position is when the screw stops turning before its head clamps.
- [ ] **M5.7** Axial play in the bearing — with the captive screw fully home, gently push and pull on the drive plate along the shaft axis; measure the total movement. Or use feeler gauges to find the larger of the two gaps (between drive plate and captive-screw head; between drive plate and thumbwheel left face). Should be small but non-zero. **This is the design feature.**

---

## Phase 6 — Depth lock

- [ ] **M6.1** Depth-lock bolt total length.
- [ ] **M6.2** Depth-lock bolt thread (should match M3.12).
- [ ] **M6.3** Depth-lock bolt tip geometry — flat, cone, cup, dog point.
- [ ] **M6.4** Does the shaft show a wear mark on its underside where the depth-lock bolt bears? Photograph.
- [ ] **M6.5** Depth-lock knob diameter and thickness; knurl style.

---

## Phase 7 — Travel and range checks (global sanity)

- [ ] **M7.1** Full shaft Y travel — from thumbwheel-rotated-all-one-way to all-the-other-way. **Don't force past either end stop.**
- [ ] **M7.2** Edge-margin range — measured as the distance from the working face to the centre of the *near* blade, at both extremes of Y travel.
- [ ] **M7.3** Spacer range supported — minimum and maximum spacer thickness the slot + grub-screw advance can accommodate.
- [ ] **M7.4** Blade projection range — how far the blades can sit below the bottom of the shaft before they bottom out somehow, or before the grub screw can no longer clamp them effectively.

---

## Phase 8 — Materials, finish, marks

- [ ] **M8.1** Material confirmation — magnet test on each part.
- [ ] **M8.2** Finish observations — overall texture, polish level, patina, any signs of original lacquer.
- [ ] **M8.3** Maker's marks, stamps, hallmarks — transcribe with location. Pencil rubbings for anything faint.
- [ ] **M8.4** Anything else clever or unusual that the spec and diagram don't already capture.

---

## After measurement — feeding back into the spec

Most measurements map directly to a symbol in §4 of the spec (`t_b`, `gap_bores`, etc.). Where the original is in imperial units, convert to mm and then round to a sensible metric value, flagging the rounding (e.g. "original 0.030 in. = 0.76 mm; specified as 0.80 mm to match standard ground blade stock"). Note any rounding decisions explicitly when filling in the spec, so the draftsman knows which numbers came straight off the original and which are interpretations.

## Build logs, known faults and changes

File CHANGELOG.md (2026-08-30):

# Changelog

All notable changes to this project are documented here.
This file is auto-updated by the release workflow on every tagged release.

---

## v0.2.0 (2026-06-30)

## What's Changed
* Add sandwich (Option B) case: thin shell + slide-in insert by @pzfreo in https://github.com/pzfreo/gramil/pull/79
* Revert drive screw to brass; both knurls 0.8 mm; ruff cleanup by @pzfreo in https://github.com/pzfreo/gramil/pull/80
* shaft: 1.5 mm chamfer on the +X (grub-screw) end OD corner by @pzfreo in https://github.com/pzfreo/gramil/pull/81
* Fix grub-screw length + size case to real asymmetric cutter travel by @pzfreo in https://github.com/pzfreo/gramil/pull/82
* Push-rod length (err long, 46.6 mm) + CNC RFQ update by @pzfreo in https://github.com/pzfreo/gramil/pull/84
* Thin the case ~4 mm: relocate the drive-train magnet off its corner by @pzfreo in https://github.com/pzfreo/gramil/pull/83

**Full Changelog**: https://github.com/pzfreo/gramil/compare/v0.1.14...v0.2.0

---

---

## v0.1.14 (2026-06-27)

## What's Changed
* Derive depth-lock push-rod length from geometry, err long by @pzfreo in https://github.com/pzfreo/gramil/pull/72
* Extend shaft for drive-screw/blade clearance; model real 25.5 mm screw by @pzfreo in https://github.com/pzfreo/gramil/pull/73
* Drive-screw captive bearing: integral journal + washer by @pzfreo in https://github.com/pzfreo/gramil/pull/75
* Drawings: thumbwheel + drive plate for the journal bearing (closes #74) by @pzfreo in https://github.com/pzfreo/gramil/pull/76
* Shaft drawing: call out the blade-slot position by @pzfreo in https://github.com/pzfreo/gramil/pull/77
* Thumbwheel + drive screw → 303 stainless (was brass) by @pzfreo in https://github.com/pzfreo/gramil/pull/78

**Full Changelog**: https://github.com/pzfreo/gramil/compare/v0.1.13...v0.1.14

---

---

## v0.1.13 (2026-06-11)

## What's Changed
* fix: shank slot-leader overlap + geometry-precise interference guard by @pzfreo in https://github.com/pzfreo/gramil/pull/69
* Update release workflow actions to node24-runtime versions by @pzfreo in https://github.com/pzfreo/gramil/pull/70
* Move Ra label clear of tip-chamfer leader on depth-lock bolt by @pzfreo in https://github.com/pzfreo/gramil/pull/71

**Full Changelog**: https://github.com/pzfreo/gramil/compare/v0.1.12...v0.1.13

---

---

## v0.1.12 (2026-05-28)

## What's Changed
* fix: increase brim_object_gap to 0.25 mm to stop brim fusing to part by @pzfreo in https://github.com/pzfreo/gramil/pull/67
* fix: revert brim_object_gap to 0.15 mm now that acceleration is fixed by @pzfreo in https://github.com/pzfreo/gramil/pull/68

**Full Changelog**: https://github.com/pzfreo/gramil/compare/v0.1.11...v0.1.12

---

---

## v0.1.11 (2026-05-28)

## What's Changed
* fix: make brim easier to remove from the case by @pzfreo in https://github.com/pzfreo/gramil/pull/66

**Full Changelog**: https://github.com/pzfreo/gramil/compare/v0.1.10...v0.1.11

---

---

## v0.1.10 (2026-05-27)

## What's Changed
* fix: use Generic PLA @base instead of Bambu PLA Basic by @pzfreo in https://github.com/pzfreo/gramil/pull/65

**Full Changelog**: https://github.com/pzfreo/gramil/compare/v0.1.9...v0.1.10

---

---

## v0.1.9 (2026-05-27)

## What's Changed
* fix: use @BBL X1C filament profile instead of @base by @pzfreo in https://github.com/pzfreo/gramil/pull/64

**Full Changelog**: https://github.com/pzfreo/gramil/compare/v0.1.8...v0.1.9

---

---

## v0.1.8 (2026-05-27)

## What's Changed
* Engrave Chelli Strings logo on the lid top by @pzfreo in https://github.com/pzfreo/gramil/pull/56
* Update pip-hinge variant to new upstream API + Knuckle.SMALL by @pzfreo in https://github.com/pzfreo/gramil/pull/55
* pip-hinge: pivot_z_offset as a first-class HingeParams param by @pzfreo in https://github.com/pzfreo/gramil/pull/57
* README: credit original design by Brian Hart and Shem Mackey by @pzfreo in https://github.com/pzfreo/gramil/pull/58
* Add estampo.toml for reproducible P1S print pipeline by @pzfreo in https://github.com/pzfreo/gramil/pull/59
* slice.yml: run full pipeline including pack stage in CI by @pzfreo in https://github.com/pzfreo/gramil/pull/60
* release: attach sliced case gcode.3mf to every release by @pzfreo in https://github.com/pzfreo/gramil/pull/61
* Add CHANGELOG.md + auto-update on every release by @pzfreo in https://github.com/pzfreo/gramil/pull/62
* CLAUDE.md: rules for trusting the user's empirical evidence by @pzfreo in https://github.com/pzfreo/gramil/pull/49
* release: fix CHANGELOG push — checkout main before pushing by @pzfreo in https://github.com/pzfreo/gramil/pull/63

**Full Changelog**: https://github.com/pzfreo/gramil/compare/v0.1.7...v0.1.8

---

---

## v0.1.7 (2026-05-25)

## What's Changed
* Prevent stale dim labels: dim_label helper + regression test by @pzfreo in https://github.com/pzfreo/gramil/pull/54

**Full Changelog**: https://github.com/pzfreo/gramil/compare/v0.1.6...v0.1.7

---

## v0.1.6 (2026-05-25)

## What's Changed
* Bone retainer: tighter waist (4.5→4.3) + shoulder fillets by @pzfreo in https://github.com/pzfreo/gramil/pull/52
* Promote blade + retainer from optional to main parts by @pzfreo in https://github.com/pzfreo/gramil/pull/53

**Full Changelog**: https://github.com/pzfreo/gramil/compare/v0.1.5...v0.1.6

---

## v0.1.5 (2026-05-25)

## What's Changed
* Print-in-place clamshell case with reference-STL hinges by @pzfreo in https://github.com/pzfreo/gramil/pull/46
* Add printable case STLs (lid + base, print-flat) by @pzfreo in https://github.com/pzfreo/gramil/pull/47
* Replace split STLs with single combined print-in-place STL by @pzfreo in https://github.com/pzfreo/gramil/pull/48
* Hinge: drop reference hinge by 2 mm instead of 3.5 mm by @pzfreo in https://github.com/pzfreo/gramil/pull/50
* Add pip-hinge variant of print-in-place case by @pzfreo in https://github.com/pzfreo/gramil/pull/51

**Full Changelog**: https://github.com/pzfreo/gramil/compare/v0.1.4...v0.1.5

---

## v0.1.4 (2026-05-22)

## What's Changed
* Sync to measured tool: shaft 35, drive screw 18, slot 6.4×4.75, bone retainer w/ fillet by @pzfreo in https://github.com/pzfreo/gramil/pull/44
* Add Prusa Open Community License (OCL v1) + README notice by @pzfreo in https://github.com/pzfreo/gramil/pull/45

**Full Changelog**: https://github.com/pzfreo/gramil/compare/v0.1.3...v0.1.4

---

## v0.1.3 (2026-05-21)

## What's Changed
* Fix CI: declare markdown-pdf + add interference tests by @pzfreo in https://github.com/pzfreo/gramil/pull/43

**Full Changelog**: https://github.com/pzfreo/gramil/compare/v0.1.2...v0.1.3

---

## v0.1.1 (2026-05-21)

## What's Changed
* RFQ tighten per shop review by @pzfreo in https://github.com/pzfreo/gramil/pull/40
* Drive screw 18→28 mm; shank fillet that actually applies by @pzfreo in https://github.com/pzfreo/gramil/pull/41

**Full Changelog**: https://github.com/pzfreo/gramil/compare/v0.1.0...v0.1.1

---

## v0.1.0 (2026-05-20)

## What's Changed
* Bootstrap parametric shank model with build123d pipeline by @pzfreo in https://github.com/pzfreo/gramil/pull/1
* Capture measurements of the original shank + spec corrections by @pzfreo in https://github.com/pzfreo/gramil/pull/2
* Measure blades and bone-shaped retainers; correct slot axes by @pzfreo in https://github.com/pzfreo/gramil/pull/3
* Reorient axes: Z = shank long (vertical), X = shaft, Y = third by @pzfreo in https://github.com/pzfreo/gramil/pull/4
* Clarify blade axis orientation in docstrings by @pzfreo in https://github.com/pzfreo/gramil/pull/5
* First-pass shaft build by @pzfreo in https://github.com/pzfreo/gramil/pull/6
* Measure drive train and captive bearing by @pzfreo in https://github.com/pzfreo/gramil/pull/7
* First-pass thumbwheel + drive screw (integral) by @pzfreo in https://github.com/pzfreo/gramil/pull/8
* Build remaining parts and assemble the full cutter by @pzfreo in https://github.com/pzfreo/gramil/pull/9
* Real ISO threads on FDM prototype path by @pzfreo in https://github.com/pzfreo/gramil/pull/11
* Ignore .claude/ harness state directory by @pzfreo in https://github.com/pzfreo/gramil/pull/12
* Fix blade stack model: spacer absent by default, slot_spare replaces grub_advance_remaining by @pzfreo in https://github.com/pzfreo/gramil/pull/13
* Rebuild shank drawing as ISO CNC-handoff package by @pzfreo in https://github.com/pzfreo/gramil/pull/14
* Make README.md useful (closes #15) by @pzfreo in https://github.com/pzfreo/gramil/pull/21
* Extract thread tables into gramil/threads.py API (closes #18) by @pzfreo in https://github.com/pzfreo/gramil/pull/22
* Add geometry tests (closes #17) by @pzfreo in https://github.com/pzfreo/gramil/pull/24
* Clean up shank_drawing.py lint by @pzfreo in https://github.com/pzfreo/gramil/pull/25
* Cutting pair: nominal diameter + ISO 286 fit classes by @pzfreo in https://github.com/pzfreo/gramil/pull/26
* Spec silver screw as M2 × 6 stock; tap depth derives by @pzfreo in https://github.com/pzfreo/gramil/pull/27
* Refactor shank_drawing.py to use build123d_drafting helpers by @pzfreo in https://github.com/pzfreo/gramil/pull/28
* Drop leader workaround (build123d-drafting-helpers 0.1.2) by @pzfreo in https://github.com/pzfreo/gramil/pull/29
* Shank drawing: fix slot width placement + add slot depth callout by @pzfreo in https://github.com/pzfreo/gramil/pull/30
* Add shaft drawing (GRM-02) by @pzfreo in https://github.com/pzfreo/gramil/pull/31
* Extract shared drawing infrastructure into gramil/parts/_drawing.py by @pzfreo in https://github.com/pzfreo/gramil/pull/32
* Add thumbwheel drawing (GRM-03); rename silver_screw → captive_screw by @pzfreo in https://github.com/pzfreo/gramil/pull/33
* Bump shaft tenon to 1.5 × 3.0 mm by @pzfreo in https://github.com/pzfreo/gramil/pull/34
* Add depth-lock bolt collar + tip chamfer (with matching shank bore) by @pzfreo in https://github.com/pzfreo/gramil/pull/35
* Drive plate drawing (GRM-04) + swap tenon onto plate by @pzfreo in https://github.com/pzfreo/gramil/pull/36
* Depth-lock bolt drawing (GRM-05); push rod ⌀5 → ⌀4.5 by @pzfreo in https://github.com/pzfreo/gramil/pull/37
* Sync specification.md with current model by @pzfreo in https://github.com/pzfreo/gramil/pull/38
* Assembly drawing (GRM-00) with exploded view + BOM by @pzfreo in https://github.com/pzfreo/gramil/pull/39

## New Contributors
* @pzfreo made their first contribution in https://github.com/pzfreo/gramil/pull/1

**Full Changelog**: https://github.com/pzfreo/gramil/commits/v0.1.0

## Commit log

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2026-05-18 Rework shank drawing for genuine eng-drawing quality
    Second pass on the A4 landscape sheet:
    - Shank long axis (X) horizontal in every orthogonal view; fits A4
    landscape much better than the previous vertical layout.
    - Hidden lines (dashed) added via project_to_viewport's hidden output,
    on their own ExportSVG layer with HIDDEN line type. Side view now
    clearly shows both bores' Y extents and the depth-lock bore at the
    X centerline.
    - Dimension lines on a dedicated layer in dashed blue (ISO_DASH line
    type, thin), distinct from the continuous-thick part lines.
    - Iso view scaled 0.5 (1:2) so it fits in the upper-right corner
    without overrunning the frame.
    - Title block tightened: tit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
2026-05-18 Capture measurements of the original shank + corrections
    Direct measurements off the original tool flip a dozen ESTIMATEs to
    MEASURED and surface several spec errors:
    Dimensions:
    - shank.length: 100 -> 80 mm
    - shank.width: 24 -> 13.55 mm (including 2.15 mm convex sagitta)
    - shank.depth: 28 -> 11 mm
    - shaft.outer_diameter: 10 -> 7.9 mm
    - drive_screw.thread: M4 -> M3
    - depth_lock.thread: M4 -> M6
    - crossbore_position_from_top: 16 -> 14 mm
    - crossbore_to_tapped_bore_gap: 10 -> 9.5 mm (DERIVED from measured
    tapped-bore-position-from-top = 4.5 mm)
    - relief_slot_width: 6 -> 2 mm
    - working_face_radius: 200 -> 8.11 mm (derived from sagitta 2.15 over
    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
2026-05-18 Measure blades, bone retainers, and answer spec Q3 (shaft has a flat)
    Blades and channel spacer:
    - blade.thickness: 0.8 -> 0.7 mm (MEASURED)
    - blade.width: 5 -> 4 mm (MEASURED)
    - blade.length: 22 -> 23 mm (MEASURED)
    - blade.tip_shape: NEW, "round" (MEASURED — luthier confirms)
    - Spec correction: blade has a single bevel and rounded end.
    Bone-shaped copper retainers (NEW PART — missing from spec):
    - New BladeRetainerParams sub-model captures the 4 bone-shaped copper
    pieces shipped with the tool. Each is 10 mm long Z (now along shaft Y
    axis after axis swap), 5.5 mm wide at the ends, 4.5 mm in the middle,
    0.75 mm thick. Sit in the slot's Y direction with two retainers on
    each side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
2026-05-18 Clarify blade axis orientation in docstrings
    Make the blade dimension docstrings explicit about which build123d
    axis each dimension occupies when the blade is seated in the slot:
    - thickness (0.7 mm): X direction, along the shaft, what the grub
    screw pushes against.
    - width (4 mm): Y direction, perpendicular to the shaft.
    - length (23 mm): Z direction, vertical when in use — longer than
    the slot's Z extent so the blade drops through and projects below
    for cutting.
    Old docstrings only specified the grub-screw face for thickness and
    were ambiguous about width vs length. Important for the upcoming
    shaft build (task #2) where we'll position blades in the slot.
    Loosened tes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
2026-05-18 Shaft measurements + design changes
    Measurements:
    - shaft.end_to_slot_distance: 8 -> 4 mm (MEASURED)
    - shaft.flat_depth: 0.7 -> 0.6 mm (MEASURED — sagitta of cylinder
    segment removed from the bottom)
    Design corrections:
    - Grub-screw end tap goes ALL THE WAY to the slot — there is no wall
    between the tap and the slot. The grub screw's tip directly
    contacts the blade stack. Spec §4.2.14 rule does not apply to this
    tool's design. Removed:
    * shaft.end_tap_depth field (now equals end_to_slot_distance,
    computed in shaft.py)
    * shaft_wall_around_end_tap computed_field
    * §4.2.14 validator
    * test_shaft_wall_around_end_tap
    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
2026-05-18 Egg-shaped drive plate with tenon anti-rotation; dome radius bump
    Drive plate (task #4 first pass):
    - New gramel/parts/drive_plate.py.
    - Proper egg outline: two circles (10 mm shaft end, 5 mm thumb end)
    connected by external tangent lines, not a peanut union.
    - 2.5 mm thick (was 2.0 in spec, but we need extra for the slot to
    leave 1.5 mm front-face wall).
    - Two clearance holes: 2.4 mm mount hole (M2 standard clearance,
    0.2 mm radial) at the shaft end, 2.4 mm silver-screw hole at the
    thumb end (0.2 mm radial — sufficient for non-binding bearing).
    - Horizontal anti-rotation slot across the FULL plate width at Z=0,
    1 mm deep into the back face. Mates with a matching tenon on the
    s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
2026-05-18 Measure drive train and captive bearing
    Drive screw + thumbwheel + silver-screw bearing:
    - drive_screw.length: 25 -> 18 mm (MEASURED)
    - drive_screw.thread_pitch: 0.5 mm now MEASURED
    - drive_screw.left_face_tap: M2 confirmed MEASURED
    - drive_screw.left_face_tap_depth: 4 mm now MEASURED
    - thumbwheel.diameter: 18 -> 10 mm (measured 9.5, rounded to 10 for
    prototype convenience — user noted 9 or 10 are both fine)
    - thumbwheel.thickness: 5 -> 2 mm (MEASURED)
    - silver_screw.thread: M2 confirmed MEASURED
    - captive_bearing.axial_play: 0.2 mm now MEASURED — the signature
    non-binding gap.
    Left as ESTIMATE intentionally:
    - blade.bevel_angle: per luthier when sharpening blades
    - silver_screw.hea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
2026-05-18 Captive-bearing geometry: tap depth, bosses, plate dims
    Silver-screw bearing safety:
    - drive_screw.left_face_tap_depth: 4 -> 3 mm. The silver-screw tap
    ends 0.5 mm into the unthreaded section now; preserves ≥1.5 mm of
    solid material before the M3 thread starts (so the tap can't eat
    into the drive-screw thread).
    - New drive_screw.unthreaded_length (3 mm) and unthreaded_diameter
    (5 mm) — the collar between the thumbwheel disc and the M3 thread.
    - New thumbwheel.silver_boss_length (0.5 mm) and silver_boss_diameter
    (6 mm) — small outboard boss on the thumbwheel where the silver-
    screw tap enters.
    Drive-plate corrections (I was giving diameters as radii):
    - drive_plate.shaft_en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
2026-05-18 Build remaining parts and assemble the full cutter
    Adds the seven parts still missing from the assembly:
    - blade (single-bevel round-end, 0.7×4×23 mm)
    - channel_spacer (1.5 mm shim, user-supplied)
    - blade_retainer (bone-shaped copper, 4 per tool)
    - grub_screw (M4×10 cylinder)
    - silver_screw (M2 head + thread sized to bottom on the
    thumbwheel tap, leaving the captive-bearing axial play)
    - depth_lock_bolt (M6 thread + knurled knob)
    - push_rod (∅5×45.5 steel rod)
    Updates assembly.py to position every part in the shank's
    frame (Z = shank, X = shaft, Y = tool-travel) so the STEP
    exports as a single complete cutter.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
2026-05-18 Model real ISO threads on the FDM prototype path
    Adds _threads.py with two helpers:
    - external_thread_section: core cylinder at the thread's minor radius
    + the helical thread fused on top.
    - internal_thread_cutout: void shape for a tapped bore — a clearance
    bore at thread major minus the helical ribs. Caller subtracts this
    from the host. Single-boolean approach avoids the body-loss glitch
    where add-thread-to-Compound drops the host material.
    Gated on process.prototype (existing flag). prototype=True (FDM print)
    gets real M3, M6, etc. helices on the drive screw, depth-lock bolt,
    shank tapped bore, and shank depth-lock threaded section. prototype=
    False (CNC) keeps the c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
2026-05-19 Pin Python to 3.12 and require build123d/bd-warehouse by default
    cadquery-ocp only ships wheels for cp312/cp313 so 3.14 (uv's current
    default) can't resolve. Tightening to >=3.12,<3.13 forces uv to pick
    3.12 on first sync.
    Also moves build123d and bd-warehouse out of the [cad] optional extra
    and into the main dependency list — there's no path through this
    project that doesn't need them, and the extra was just a tripwire.
2026-05-19 Fix blade stack model: spacer is absent by default, not 1.5 mm
    The default tool state has no channel spacer installed — just 4 retainers
    (0.75 mm each) + 2 blades (0.7 mm each), leaving ~1.6 mm of air gap for
    grub-screw advance. The previous default of spacer.thickness=1.5 mm was
    wrong and made the slot appear almost fully packed (0.1 mm spare).
    Changes:
    - SpacerParams.thickness default 1.5 → 0.0, gt → ge (allows zero)
    - stack_thickness now returns hardware-only (4×retainer + 2×blade = 4.4 mm)
    - Replace grub_advance_remaining with slot_spare = slot_width − stack_thickness
    - Assembly skips the spacer part when thickness == 0
    - Update tests to match corrected values (stack=4.4, spar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
2026-05-19 Rebuild shank drawing as ISO CNC-handoff package
    Replaces the build123d.TechnicalDrawing frame (which forces a 6×4 grid
    of letters/numbers and a half-page-sized title block) with a custom ISO
    5457 A4 landscape layout: thin border, 4 centering marks, 100×50 mm
    ISO 7200-style title block bottom-right, and a notes block above it.
    Drawing-side robustness:
    - _dim_outside(p1, p2, side, distance, ...) wraps ExtensionLine and
    computes the offset sign automatically from a "left"/"right"/
    "above"/"below" argument. No more guessing offsets — verified
    empirically and documented in CLAUDE.md.
    - _leader(feature, direction, label, ...) returns (lines, text) as
    separate Compounds so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
2026-05-19 Extract thread tables into gramel/threads.py API
    Moves _THREAD_MAJOR_RADIUS, _TAP_DRILL_DIAMETER, and _THREAD_PITCH out
    of parameters.py into a dedicated gramel/threads.py module with a small
    public API:
    threads.major_radius(thread)
    threads.major_diameter(thread)
    threads.tap_drill_radius(thread)
    threads.tap_drill_diameter(thread)
    threads.pitch(thread)
    threads.known_threads()
    A single underlying _TABLE drives all three columns so they cannot drift
    relative to each other.
    Unknown thread specs now raise a ValueError listing every valid entry,
    instead of a bare KeyError or a "extend _THREAD_MAJOR_RADIUS" hint that
    no longer reflects the real fix.
    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
2026-05-19 Add geometry tests for every part
    29 tests that build each part and assert nonzero volume + bounding box
    matches the expected dimensions (axes derived from the documented
    local-frame convention of each module). Plus feature-position
    sanity for the shank crossbore/tapped bore, the shaft slot, and the
    captive-bearing axial play.
    All tests run with process.prototype=False (CNC mode, smooth cylinders)
    so the full suite finishes in ~9 s. The real-thread FDM path is not
    exercised here (would add minutes per test) — separate concern.
    Catches: zero-volume regressions from bad booleans; axis swaps in
    build_<part>() functions; bores merging because crossbore_to_tapped_bore_gap
    got too small; flat-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
2026-05-19 Cutting pair: nominal diameter + ISO 286 fit classes
    Replaces the shaft.outer_diameter + cnc_sliding_clearance pair with a
    single cutting-pair nominal diameter and per-side ISO 286 fit classes.
    Standard machinist practice: pick a stock H7 reamer size for the bore
    and lathe the shaft to fit.
    Parameters
    ----------
    New CuttingPairParams on PurflingCutterParams:
    - nominal_diameter (default 8.0 — picked to match a standard H7
    reamer; the original tool measured 7.9 mm but was rounded up)
    - bore_fit = "H7" (shank crossbore)
    - shaft_fit = "g6" (shaft OD)
    Removed:
    - ShaftParams.outer_diameter — replaced by params.shaft_outer_diameter
    computed_field (= cutting_pair.nominal_diame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
2026-05-19 Refactor shank_drawing.py to use build123d_drafting helpers
    Replaces the hand-rolled `_dim_outside` (side-driven dim wrapping
    ExtensionLine.offset's right-hand-rule signs) and `_leader` helpers
    with the published `dim_linear` and `leader` from build123d-drafting-
    helpers. Saves ~100 lines (577 → 480) and inherits the library's
    offset-sign handling and label-extraction work.
    Custom page frame, title block, and notes block stay local because
    the library's `iso_title_block` (170 × 16 mm, 2-row) has a different
    shape than our 100 × 50 mm bottom-right corner block.
    One known upstream bug worked around: the helper's `leader.lines`
    shape extends past the elbow and strikes through the label te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
2026-05-20 Fix slot width placement + add slot depth callout
    The slot width "2.0" dim was sitting above the top of the face view —
    visually adjacent to the top of the shank, where the slot doesn't
    actually reach (it terminates at the crossbore, 14 mm down from the
    top). Moved the dim to BELOW the face view, stacked under the depth
    "11.0" dim, so witness lines drop from the slot's two X edges straight
    down to where the slot actually opens at Z=0.
    Added a slot depth callout — "slot 1 deep" — as a leader on the side
    view pointing into the 1 mm notch on the working-face side. The slot
    depth wasn't dimensioned anywhere before.
2026-05-20 Stack face-view dims feature-first; bump side-view dims to clear leaders
    Face view: slot width (2.0) now sits closer to the view than the depth
    (11.0). ISO convention is feature dim first, overall dim further out.
    The previous order had them swapped so the labels visually crowded.
    Side view: threaded-length and smooth-length dim lines pushed out from
    distance 14/20 to 32/38, and the leader anchor pulled in from
    s_right+28 to s_right+16. Result: leader lines (⌀5.0 H8, M6×1) now
    terminate well before they reach the dim lines — no more dim-vs-leader
    crossings or labels-overwriting-each-other.
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2026-05-20 Add thumbwheel drawing (GRM-03); rename silver_screw → captive_screw
    The drawing review surfaced two naming issues: the "silver boss" is
    machined from the same brass stock as the rest of the thumbwheel (the
    "silver" was leftover from the historical name of the screw it hosts),
    and the "silver screw" is just a stock M2 fastener — its silver-coloured
    appearance versus the brass around it isn't load-bearing on the design.
    Rename throughout:
    silver_boss_diameter / silver_boss_length → boss_diameter / boss_length
    silver_screw → captive_screw (the screw that creates the captive bearing)
    SilverScrewParams → CaptiveScrewParams
    silver_clearance_hole_diameter → captive_clearance_h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
2026-05-20 Bump shaft tenon to 1.5 × 3.0 mm (was 1.0 × 2.0)
    Production-engineer feedback on the drive-plate ↔ shaft joint: the
    1×2 mm tenon was small enough that a CNC shop could push back on it
    as a fiddly milling op. Bumped to 1.5 deep × 3.0 tall, still leaves
    1.5 mm of wall on the plate's front face (plate is 3 mm thick). The
    slot mill op on the plate becomes a more forgiving cut.
    Also fix two label format issues in shaft_drawing surfaced by the
    size change:
    - "tenon {tenon_depth:.0f} proj" rounded 1.5 → "2"; use .1f.
    - Tenon Z dim with label "3" and 3 mm path hits an empty-wire crash
    in build123d's DimensionLine (specific path-length / label-width
    ratio). Workaround: format as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
2026-05-20 Add drive plate drawing (GRM-04); swap tenon onto plate, slot onto shaft
    Three related changes:
    1. Add `drive_plate_drawing.py` — A4 landscape CNC handoff drawing at
    3:1 scale, face/side/iso views with dim stack + leader callouts.
    2. Bump captive-bearing clearance hole 2.4 → 2.6 (was always meant to
    be "deliberately sloppy ~0.3 mm radial" per the original drive_plate
    docstring, but the param was sitting at the same 2.4 as the mount
    hole). Drawing now has separate callouts for the two holes:
    ⌀2.4 mount (big boss)
    ⌀2.6 captive bearing (small boss)
    3. Swap the anti-rotation tenon onto the plate and the matching slot
    into the shaft. The plate now keeps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
2026-05-20 Drive plate tenon: full 8 mm width; mount hole drills through
    Two refinements to the tenon swap:
    - tenon_width 6 → 8 mm. Goes across the full shaft diameter (same
    as the original shaft tenon used to), so the slot can be milled
    in one pass on both parts and the tenon engages the entire slot
    width with no slop.
    - Build the tenon BEFORE drilling the mount hole so the M2
    clearance hole passes cleanly through both the plate and the
    tenon. Otherwise the screw would have hit a solid wall of tenon
    on its way to the shaft tap.
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2026-05-20 Add depth-lock bolt drawing (GRM-05); push rod ⌀5 → ⌀4.5
    GRM-05 — A4 landscape CNC drawing for the depth-lock bolt + knurled
    knob. 2:1 scale, drawn horizontal with the knob on the left. Chained
    dim stack above (14 + 5 + 13 = 32). Leader callouts for the knurl,
    collar (⌀6.25), thread spec (M6 × 1), Ra 1.6 on thread, and
    0.5 × 45° lead-in chamfer on the tip. End view shows the knob; iso
    view shows the stepped profile.
    Push rod ⌀5 → ⌀4.5. The bore the rod slides in is the M6 tap drill
    diameter (⌀5), and a ⌀5 rod in a ⌀5 bore won't slide. ⌀4.5 in ⌀5
    gives 0.25 mm radial clearance — comfortable sliding fit.
2026-05-20 Validate depth-lock sliding fits (push rod, bolt collar)
    Two pairs of features inside the depth-lock bore need clearance to
    slide. The constraint had been only in field descriptions — moved to
    an enforceable model_validator with matching tests:
    - push_rod_diameter < depth_lock_bore_diameter
    - bolt_collar_diameter < depth_lock_collar_bore_diameter
    Minimum clearance 0.05 mm diametric for both. Violations raise
    ValidationError at model construction time, so a user can't quietly
    set push_rod=5 against a 5 mm bore again.
2026-05-20 Collar bore 5.0 → 5.5 mm; enforce 0.3 mm length margin over the collar
    The bore was exactly as long as the bolt collar, so manufacturing
    tolerance on either feature could land the collar's top against the
    tap shoulder. Bumped the bore to 5.5 mm (0.5 mm design margin) and
    added a validator that requires bore ≥ collar + 0.3 mm.
    Trade-off: tap section shifts up by 0.5 mm so thread engagement
    drops from 12.0 → 11.5 mm at the lock position. Still ample.
2026-05-20 Spec sync — bring specification.md in line with the current model
    The spec had drifted significantly behind the model since the egg-shape
    drive plate, the tenon/slot swap, the captive-bearing rename, the bolt
    collar + chamfer, and the push-rod sizing all landed. Updated:
    §2 Glossary
    - Drive plate: now described as egg-shaped with two bosses, central
    mount + tenon, captive-screw clearance hole.
    - Depth-lock bolt: now describes the unthreaded collar and tip chamfer.
    - Depth-lock push rod: ⌀4.5 / ⌀5 bore sliding fit.
    §4.2 (Shaft) item 19
    - Drive plate mounting was 'two tapped holes' — now one central tap +
    a slot for the plate's tenon.
    §4.3 (Shank) items 30, 30a, 3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
2026-05-24 Ship single combined print-in-place case STL
    Replaces the two separate lid/base STLs with the single combined
    print-in-place STL: both halves in one file in print-flat orientation
    with the cropped reference hinge merged in. This is the file to drop
    straight into a slicer.
    Regenerate with: uv run python tools/assemble_case_with_reference_hinge.py
    [case_base_print.stl, case_lid_print.stl, case_print_in_place.stl]
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2026-05-24 Hinge: drop reference hinge by 2 mm instead of 3.5 mm
    The reference Oral-B hinge was dropped 3.5 mm to bring its native
    12.5 mm height down to fit our 8 mm case half. That dropped the
    side-plate top to print z = 6.5 mm — 1.5 mm below the case top —
    so the lid binds against the base during closing motion. The hinge
    itself prints and pivots correctly, but the case can't fully close.
    Cropping at ref z=2 instead of 3.5 (and dropping by the same amount)
    lands the full-width side-plate top at print z = 8 mm, flush with
    the case top. The teardrop pivot + apex protrude 2.5 mm above, which
    is the geometry that makes the clamshell pivot cleanly.
    The narrow tab between ref z=2 and z=3.5 is intent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
    [case_print_in_place.stl]
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2026-05-26 Update pip-hinge variant to new upstream API with Knuckle.SMALL
    Upstream pip-hinge has been redesigned around four case-designer inputs
    (case_h, hinge_length, stations, knuckle). Re-vendor the new hinge.py
    and port the assemble script to the new API.
    This switches the gramel pip-hinge variant from the old Ø6 ad-hoc
    knuckle to the new Knuckle.SMALL preset:
    - Po (knuckle Ø) = max(case_h/2, 5 mm) = 5 mm at case_h=8
    - W (leaf depth) = Ro + mounting_flat = 2.5 + 0.5 = 3 mm
    - Ramp angle ~22° from vertical (vs ~45° for HALF, vs no ramp for FULL)
    - Auto-tightened clasp_clearance = 0.2 mm (matches r0berts' original)
    - Combined bbox height drops from 11 mm to 10.5 mm (smaller knuckle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
    [case_print_in_place_pip_hinge.stl]
2026-05-26 Engrave Chelli Strings logo on lid + rotate 90° CW + shorter hinges
    Three changes bundled into the lid-logo-engraving branch:
    1. Engrave "Chelli\nStrings" into the lid's outer-top face using the
    Mrs Saint Delafield Regular calligraphic script — matching the
    pzfreo/pegturner branding. Each line is V-tapered (45° / 30° /
    20° / 10° fallback chain) so the cavity prints self-supporting
    when the lid lays face-down.
    2. Rotate the engraved text 90° CW about the lid-top normal — the
    case now reads naturally when held with its long edge upright.
    New CaseParams.logo_rotation knob (default -90°).
    3. Shorten the pip-hinge clusters to 2/3 length with 2 fewer stations:
    HI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
    [case_print_in_place_pip_hinge.stl]
2026-05-26 Make pip-hinge variant the default printable case; rename Oral-B to alt
    The pip-hinge variant (Knuckle.SMALL, two shorter hinges, Chelli Strings
    logo engraved on the lid) is now the default print-in-place case shipped
    at gramel/case/printable/case_print_in_place.stl. The Oral-B reference
    hinge variant is preserved as the only alternative, renamed to
    case_print_in_place_oralb.stl.
    No code or geometry changes — pure rename + docstring update.
    [case_print_in_place.stl, case_print_in_place_oralb.stl, case_print_in_place_pip_hinge.stl]
2026-05-26 pip-hinge: add pivot_z_offset as a first-class HingeParams param
    Upstream pip-hinge keeps PIVOT_Z_OFFSET=0.2 only in the clamshell
    *example*, applied externally by passing case_h=WALL_H+OFFSET.
    Every case designer has to re-discover the empirical lift and
    re-apply it themselves — a leaky abstraction.
    Add it as a real parameter on HingeParams with the documented
    default of 0.2 mm. Internally:
    - effective leaf height grows by pivot_z_offset (so leaf still
    reaches the bed when the axis is positioned at case_h)
    - the hinge body is lifted by pivot_z_offset in its local frame
    so the axis sits above the leaf-top reference
    Caller positions by case wall top as before — the hinge nat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
    [case_print_in_place.stl]
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2026-08-30 chore: rename gramel to gramil throughout
    The project has been renamed on GitHub from pzfreo/gramel to
    pzfreo/gramil. This brings the tree in line.
    - `gramel/` -> `gramil/` (git mv, rename detection preserved)
    - every textual occurrence of gramel/Gramel replaced: package imports,
    pyproject name and hatch packages, uv.lock, estampo.toml, the release
    workflow's artifact names, .gitignore's bundle glob, docs and the
    CHANGELOG's PR links, tests, scripts, tools
    Build artifact names follow the package name, so the production and
    Draftwright bundles now emit gramil_drawings.pdf, gramil_assembly.step,
    gramil_case_{shell,insert}.step and gramil-<version>*.zip. The drawing
    sheets themselves ne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
    [case_print_in_place.stl, case_print_in_place_oralb.stl, reference_hinge_base.stl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]
